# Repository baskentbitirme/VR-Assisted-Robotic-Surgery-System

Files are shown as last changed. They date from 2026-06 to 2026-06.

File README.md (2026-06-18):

TR

Eğitim ve Araştırma Uygulamaları İçin VR Destekli Robotik Cerrahi Eğitim Platformu

Bu proje, sağlık bilimleri ve mühendislik eğitiminde kullanılan yüksek maliyetli robotik sistemlere erişilebilir bir alternatif oluşturmak amacıyla geliştirilmiş hibrit bir eğitim ve araştırma platformudur. Sistem; Sanal Gerçeklik (VR), yapay zekâ destekli görüntü işleme, kablosuz haberleşme ve 3B yazıcıyla üretilmiş robotik bir kolu tek bir ekosistemde bir araya getirmektedir.

Proje kapsamında Berlin Charité Hastanesi'nden elde edilen fotogrametrik tarama verileri kullanılarak gerçekçi bir ameliyathane ortamı oluşturulmuş ve Unity tabanlı VR simülasyonuna entegre edilmiştir. Simülasyon ortamı tamamen açık kaynaklı teknolojiler, açık veri kaynakları ve açık erişimli varlıklar kullanılarak geliştirilmiştir.

Fiziksel robot kol tasarımı, açık kaynaklı BCN3D Moveo platformu temel alınarak yeniden modellenmiş ve eğitim senaryosunun ihtiyaçlarına uygun şekilde optimize edilmiştir. Orijinal çok eksenli yapı sadeleştirilerek 3 serbestlik dereceli (3-DoF) bir mimariye dönüştürülmüş ve tamamen 3B yazıcı teknolojileri kullanılarak üretilmiştir.

Sistemde iki farklı veri akışı eş zamanlı olarak çalışmaktadır. Kullanıcının VR ortamında seçtiği cerrahi alet bilgisi, XBee tabanlı kablosuz haberleşme altyapısı üzerinden fiziksel sisteme aktarılır. Aynı anda Grove Vision AI ve YOLOv8 tabanlı görüntü işleme sistemi çalışma alanındaki cerrahi aletleri gerçek zamanlı olarak algılar ve konum bilgilerini üretir. Merkezi kontrol birimi, VR tarafından gönderilen hedef nesne bilgisi ile yapay zekâ sisteminden gelen konum verilerini eşleştirerek robot kolun doğru nesneyi kavramasını ve doğru hedef noktaya taşımasını sağlar.

Bu yaklaşım sayesinde proje yalnızca bir VR simülasyonu veya yalnızca bir robot kol çalışması olmaktan çıkarak; sanal ortam, yapay zekâ algılama sistemi ve fiziksel robotu gerçek zamanlı olarak birleştiren bir Dijital İkiz (Digital Twin) platformuna dönüşmektedir.

Kullanılan Başlıca Teknolojiler

- Unity 6
- OpenXR
- YOLOv8
- Grove Vision AI V2
- XBee (IEEE 802.15.4)
- Arduino Mega
- ESP32
- BCN3D Moveo (Open Source Reference Architecture)
- Fusion 360
- 3D Printing Technologies

Proje Ekibi

Ayşe Sena ŞAHİN

Ceren Sena ALTUĞ

Nehir DÖLER

Nehir ERDEN

Sıla Nur SÖNMEZ

Yiğit Kemal YEŞİLTAŞ

Danışmanlar

Prof. Dr. Sedat NAZLIBİLEK

Prof. Dr. Ziya TELATAR

Dr. Öğr. Üyesi Onur KOÇAK

Not

Bu proje geliştirilirken literatür araştırması, yazılım geliştirme, hata ayıklama, dokümantasyon ve teknik doğrulama süreçlerinin çeşitli aşamalarında yapay zekâ araçlarından destek alınmıştır.

--------------------------------------------------------------

EN

VR-Assisted Robotic Surgical Training Platform for Educational and Research Applications

This project is a hybrid educational and research platform developed as an accessible alternative to high-cost robotic systems used in healthcare and engineering education. The system combines Virtual Reality (VR), AI-powered computer vision, wireless communication, and a 3D-printed robotic arm within a single integrated ecosystem.

A realistic operating room environment was reconstructed using photogrammetric data acquired from Berlin Charité Hospital and integrated into a Unity-based VR simulation. The virtual environment was developed entirely using open-source technologies, open datasets, and openly available digital assets.

The physical robotic arm was redesigned based on the open-source BCN3D Moveo platform and optimized for the educational objectives of the project. The original multi-axis architecture was simplified into a three-degree-of-freedom (3-DoF) robotic system and manufactured using additive manufacturing technologies.

The system operates through two simultaneous data streams. The surgical instrument selected by the user inside the VR environment is transmitted to the physical platform via an XBee-based wireless communication network. At the same time, a Grove Vision AI and YOLOv8-powered perception system continuously detects surgical instruments within the workspace and generates real-time positional data. The central control unit correlates the target object selected in VR with the position data provided by the AI vision system, enabling the robotic arm to identify, grasp, and transport the correct instrument to the designated destination.

By combining immersive VR interaction, AI-based perception, and physical robotic actuation, the project goes beyond a conventional simulation environment and evolves into a Digital Twin platform where virtual and physical systems operate synchronously in real time.

Key Features

- Photogrammetry-based Operating Room Reconstruction
- Virtual Reality Surgical Training Environment
- Digital Twin Architecture
- AI-Powered Object Detection and Localization
- Real-Time Wireless Communication
- Autonomous Instrument Identification and Handling
- Open-Source-Based Robotic System Design
- Low-Cost and Reproducible Educational Platform

Technologies

- Unity 6
- OpenXR
- YOLOv8
- Grove Vision AI V2
- XBee (IEEE 802.15.4)
- Arduino Mega
- ESP32
- BCN3D Moveo (Open-Source Reference Architecture)
- Fusion 360
- 3D Printing Technologies

Project Team

Ayşe Sena ŞAHİN

Ceren Sena ALTUĞ

Nehir DÖLER

Nehir ERDEN

Sıla Nur SÖNMEZ

Yiğit Kemal YEŞİLTAŞ

Supervisors

Prof. Dr. Sedat NAZLIBİLEK

Prof. Dr. Ziya TELATAR

Asst. Prof. Dr. Onur KOÇAK

Acknowledgement

This project was developed with support from various artificial intelligence tools during selected stages of literature review, software development, debugging, documentation, and technical validation.

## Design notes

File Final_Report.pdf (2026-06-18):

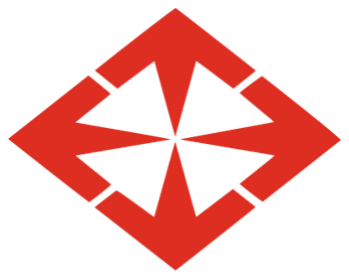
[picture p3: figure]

BAŞKENT ÜNİVERSİTESİ MÜHENDİSLİK FAKÜLTESİ BİTİRME PROJESİ RAPORU

EĞİTİM VE ARAŞTIRMA UYGULAMALARI İÇİN VR DESTEKLİ 3B

YAZICIYLA ÜRETİLMİŞ ROBOTİK CERRAHİ SİSTEMİNİN TASARIMI,

SİMÜLASYONU VE UYGULANMASI

Sıla Nur SÖNMEZ 22297548 & 22340070

Ayşe Sena ŞAHİN 22297606

Nehir DÖLER 22295597

Yiğit Kemal YEŞİLTAŞ 22298241

Ceren Sena ALTUĞ 22294442

Nehir ERDEN 22295777

Bölümü: Elektrik-Elektronik Mühendisliği

Proje Danışmanı: Prof. Dr. Sedat NAZLIBİLEK, Prof. Dr. Ziya TELATAR, Dr. Öğr. Üyesi Onur KOÇAK

Ders Kodu ve Adı: EEM 496 Bitirme Projesi II

Proje Başlangıcı: 2025-2026 Bahar Proje Süresi (Yarıyıl):2

Rapor Sunumu: 2025-2026 Bahar

i

Doküman No: MF-F-FRM-KONTROL EEM | Revizyon Tarihi: Revizyon Numarası:
Sayfa Sayısı: 1/1 | Uygulama Tarihi: 25.04.2018

BAŞKENT ÜNİVERSİTESİ MÜHENDİSLİK FAKÜLTESİ ELEKTRİK-ELEKTRONİK MÜHENDİSLİĞİ BÖLÜMÜ

BİTİRME PROJESİ RAPOR KONTROL FORMU

2025- 2026 BAHAR YARIYILI
Projenin Başlığı | Eğitim ve Araştırma Uygulamaları için VR destekli 3B Yazıcıyla Üretilmiş Robotik Cerrahi Sisteminin Tasarımı, Simülasyonu ve Uygulaması
Öğrenci | SILA NUR SÖNMEZ
Öğrenci | AYŞE SENA ŞAHİN
Öğrenci | NEHİR DÖLER
Öğrenci | YİĞİT KEMAL YEŞİLTAŞ
Öğrenci | CEREN SENA ALTUĞ
Öğrenci | NEHİR ERDEN

Ders
Kodu | EEM496
Proje | Süresi
(Yarıyıl) | 2 | Kaçıncı Yarıyıl | 2

Raporda Mutlaka Bulunması Gereken Kısımların Kontrolü:
Bölüm | Kontrol
Yazış biçimi uygun.
Dış kapak ve sunuş biçimi uygun.
Giriş bölümü var.
Yapılan çalışmayı anlatan bölümler var.
Proje çalışmasının gerçekçi kısıtlar altında yapıldığını anlatan bölümler var ve yeterli. (Proje işleyiş prosedürü genel esaslar madde 3’e göre incelenmelidir.)

Sonuçlar bölümü var.
Kaynakça var.

ii

Adı Soyadı | İmza
Proje Danışmanı | Ziya TELATAR
Proje Danışmanı | Sedat NAZLIBİLEK
Proje Danışmanı | Onur KOÇAK

iii

BİTİRME PROJESİ ONAY FORMU

Eğitim ve Araştırma Uygulamaları için VR destekli 3B Yazıcıyla Üretilmiş Robotik Cerrahi Sisteminin Tasarımı, Simülasyonu ve Uygulaması başlıklı bitirme projesi raporu kapsam ve niteliği açısından tarafımızdan incelenmiş ve kabul edilmiştir.

| Unvan- İsim Soy isim | İmza
DANIŞMAN | Prof. Dr. Sedat NAZLIBİLEK
DANIŞMAN | Prof. Dr. Ziya TELATAR
DANIŞMAN | Dr. Öğr. Üyesi Onur KOÇAK
JÜRİ ÜYESİ | Doç. Dr. Selda GÜNEY
JÜRİ ÜYESİ | Dr. Öğr. Üyesi Gülşah DEMİRHAN AYDIN
JÜRİ ÜYESİ | Dr. Öğr. Üyesi Deniz KARAÇOR
JÜRİ ÜYESİ | Dr. Öğr. Üyesi Bülent İRFANOĞLU

iv

TEŞEKKÜR

Bu çalışma sürecinde, ihtiyacımız olduğu anlarda yardımını esirgemeyen Prof. Dr. Ziya TELATAR, Prof. Dr. Sedat NAZLIBİLEK, Dr. Öğr. Üyesi Onur KOÇAK hocalarımıza ve projenin yürütülmesi sürecinde sağladıkları teknik altyapı ve destek için Marla Teknoloji Mühendislik Ltd. Şti.’ye çok teşekkür ederiz.

v

ÖZ

Günümüzde sağlık bilimleri ve mühendislik eğitiminde kullanılan yüksek maliyetli ticari robotik sistemlere erişim, kurumların büyük çoğunluğu için ciddi bir engel teşkil etmektedir. Bu çalışmada söz konusu probleme çözüm olarak; sanal gerçeklik (VR) destekli, yapay zekâ tabanlı görüntü işleme entegreli, düşük maliyetli ve yeniden üretilebilir bir robotik medikal lojistik eğitim platformu tasarlanmış, geliştirilmiş ve doğrulanmıştır.

Platformun mekanik tasarımı, açık kaynaklı BCN3D Moveo mimarisi referans alınarak Fusion 360 ortamında yeniden modellenmiş; orijinal 6 eksenli yapı, projenin gereksinimlerine göre taban, omuz ve dirsek olmak üzere 3 serbestlik dereceli (3-DoF) bir kola dönüştürülmüş ve Bambu Lab üç boyutlu yazıcı ile eSun PLA+, PLA ve ABS filamentler kullanılarak üretilmiştir. Motor konfigürasyonunda; taban ekseninde tork kararlılığı için uzun gövdeli bir Nema 17, omuz ekseninde yüksek yük kapasitesi sağlamak amacıyla paralel çalışan iki adet Nema 23 ve dirsek ekseninde 3B baskı ile üretilmiş 4:1 gezegen dişlisiyle desteklenmiş bir adet Nema 17 adımlı motor tercih edilmiştir. Uç efektördeki tutucu (gripper) mekanizması MG996R servo motor ile kontrol edilmekte; tüm motorlar RAMPS 1.4 kontrol kartı ve dört adet TB6600 sürücüsü aracılığıyla yönetilmektedir. Gömülü yazılım katmanında motorların kesintisiz ve zamanlaması hassas biçimde çalışabilmesi için donanımsal zamanlayıcı kesmesi (Timer5 Interrupt) altyapısı benimsenmiş; süreç yönetimi asenkron durum makinesi (state machine) yapısıyla kurgulanmıştır.

Sistemin genel çalışma akışı şu şekilde işlemektedir: Kullanıcı, Unity 3D oyun motoru ve OpenXR altyapısıyla geliştirilen sanal ameliyathane ortamında cerrahi aletlerle etkileşime girerek bir lojistik komut başlatır. Bu komut, VR İstasyonundan XBee modülleri (IEEE 802.15.4, nokta-nokta topoloji) aracılığıyla kablosuz olarak fiziksel robota iletilir. Eş zamanlı olarak, Grove Vision AI Modülü ve Raspberry Pi kamerasından oluşan görüntü işleme birimi, YOLOv8 modeli ile çalışma alanındaki hemostat, penset, steril kompres ve kontamine kompres gibi cerrahi aletleri gerçek zamanlı olarak tanımlar ve elde edilen (x_center, y_center) piksel koordinatlarını donanımsal seri port (Serial1) üzerinden Arduino Mega'ya iletir. Arduino Mega bu koordinatları, XBee (Serial2) üzerinden gelen taşıma emirleriyle eşleştirerek bilineer koordinat dönüşüm matematiği yardımıyla motor adım sayılarına çevirir ve robotik kol nesneyi hedef medikal sokete başarıyla yerleştirir. Tüm bu süreçte işlem yükü; VR simülasyonunu yürüten VR İstasyonu ile robot tarafındaki güç yönetimi ve kamera veri hatlarını denetleyen Yerel İzleme İstasyonu arasında dağıtık bir mimariyle paylaştırılmıştır. Seri iletişimde (UART) paket kaybını önlemek amacıyla dinamik veri çerçeve yapısı uygulanmıştır.

Geliştirilen bu hibrit platform; düşük gecikmeli kablosuz iletişim, gerçek zamanlı entegrasyon ve gelişmiş görüntü işleme yeteneklerini bir arada sunarak medikal malzeme yönetimi süreçlerinin eğitiminde güvenli, tekrarlanabilir ve erişilebilir bir alternatif oluşturmaktadır.

vi

ABSTRACT

Access to robotic training systems in health sciences and engineering education remains a practical challenge for most institutions due to the high cost of commercial alternatives. This study presents the design, development, and validation of a low-cost, reproducible robotic medical logistics training platform that combines virtual reality (VR) with AI-based visual perception.

The mechanical structure was designed in Fusion 360 by adapting the open-source BCN3D Moveo architecture, reducing the original six-axis configuration to a three-degree-of-freedom (3-DoF) arm with base, shoulder, and elbow axes. The arm was fabricated using a Bambu Lab 3D printer with eSun PLA+, PLA, and ABS filaments. A long-body Nema 17 motor drives the base axis, two parallel Nema 23 motors handle the shoulder axis for higher load demands, and a Nema 17 motor paired with a 3D-printed 4:1 planetary gearbox drives the elbow. All stepper motors are controlled through a RAMPS 1.4 board and four TB6600 drivers, while the end-effector gripper is actuated by a MG996R servo motor. On the firmware side, a hardware timer interrupt (Timer5 Interrupt) ensures precise and uninterrupted motor stepping, with overall process flow managed through an asynchronous state machine.

The system operates as follows. The user interacts with surgical instruments inside a virtual operating room built with Unity 3D and OpenXR, generating a logistics command. That command travels wirelessly from the VR Station to the physical robot over XBee modules (IEEE 802.15.4, point-to-point). At the same time, a Grove Vision AI Module and Raspberry Pi camera run a YOLOv8 model that continuously detects surgical tools including hemostats, forceps, sterile compresses, and contaminated compresses, sending their (x_center, y_center) pixel coordinates to the Arduino Mega over Serial1. The Arduino Mega correlates those coordinates with the incoming transport command from XBee (Serial2), applies bilinear coordinate transformation to convert pixel positions into motor step counts, and drives the arm to place the target object into the correct medical socket. To distribute computational load and maintain physical independence, the architecture splits responsibility between the VR Station handling simulation and a Local Monitoring Station managing power and camera data near the robot. A dynamic UART frame structure guards against packet loss throughout.

The resulting platform brings together low-latency wireless communication, real-time object detection, and immersive VR interaction in a single reproducible system, offering a practical and accessible training environment for medical material handling procedures.

vii

İÇİNDEKİLER

2.1.2. Ara dönem sonrası yapılan mimari değişiklikler ve sistem

viii

ix

2.5.1. Asenkron durum yönetimi ve komut işleme mantığı | 58
2.5.2. Ara dönem sonrası yapılan mimari değişiklikler ve gerekçeleri........58
3. PROJENİN DEĞERLENDİRİLMESİ | 60
3.1. Proje İş Planı ve Yönetimi | 60
3.2. Projenin Maliyeti ve Ekonomik Açıdan Değerlendirilmesi | 61
3.3. Kullanılan veya Dikkate Alınan Mühendislik Standartları | 64
3.4. Projenin Gerçekçi Tasarım Kriterleri Açısından Değerlendirilmesi .........65
3.4.1. Gerçekçi kısıtlar ve koşullar | 65
3.4.2. Sürdürülebilirlik | 65
3.4.3. Üretilebilirlik | 66
3.4.4. Sağlık | 66
3.4.5. Çevresel etkiler | 66
3.4.6. Güvenlik | 67
3.4.7. Etik | 67
3.4.8. Sosyal ve politik sorunlar | 67
3.4.9. Yaygınlık | 67
3.4.10. Özgünlük | 67
3.4.11. Girişimcilik | 67
3.4.12. Yenilikçilik | 68
4. SONUÇ | 69
EK-A: Kavram Tanımlama ve İşletimi (KTİD) Belgesi | 71
EK-B: Proje İsterleri Belirtimi (PİBD) Belgesi | 72
EK-C: Proje Uygulama Takvimi (PRUT) | 73
EK-D: Genel Mimari Tasarımı (PMTD) Belgesi | 76
EK-E: Proje Risk Tanımlama (PRTD) Belgesi | 77
EK-F: IEEE Etik Kuralları | 79
EK-G: Standartlar ve Kısıtlar Belgesi | 80
EK-H: Disiplinler Arası Çalışma Belgesi | 81
EK-I: Öğrenci Özgeçmişleri | 82
EK-J: Yazılım Kaynak Kodları ve Dijital Dokümantasyon | 84
KAYNAKÇA | 85

x

TABLOLAR DİZİNİ

Tablo 1 Maliyet Analizi Bölüm 1 | 62
Tablo 2 Maliyet Analizi Bölüm 2 | 62
Tablo 3 Maliyet Analizi Bölüm 3 | 63
Tablo 4 Maliyet Analizi Bölüm 4 | 63
Tablo 5 Maliyet Analizi Bölüm 5 | 64
Tablo 6 Proje Uygulama Takvimi Bölüm 1 | 73
Tablo 7 Proje Uygulama Takvimi Bölüm 2 | 74
Tablo 8 Proje Uygulama Takvimi Bölüm 3 | 75
Tablo 9 Risk Analizi Bölüm 1 | 77
Tablo 10 Risk Analizi Bölüm 2 | 77
Tablo 11 Risk Analizi Bölüm 3 | 78

xi

ŞEKİLLER DİZİNİ

xii

SİMGELER VE KISALTMALAR DİZİNİ

3B / 3D: Üç Boyutlu
ADC (Analog-to-Digital Converter): Analog-Dijital Dönüştürücü
API (Application Programming Interface): Uygulama Programlama Arayüzü
BAUD: Seri Haberleşme Hız Birimi (115200 Baud vb.)
CAD (Computer Aided Design): Bilgisayar Destekli Tasarım
C# (C-Sharp): Unity platformu içerisinde kullanılan programlama dili
COM (Communication Port): Bilgisayar üzerindeki seri haberleşme portu DoF (Degrees of Freedom): Serbestlik Derecesi (Robot kolun hareket ekseni sayısı)
FPS (Frames Per Second): Saniyedeki Kare Sayısı (Simülasyonun akıcılık değeri)
GND (Ground): Elektriksel Topraklama
GUI (Graphical User Interface): Grafik Kullanıcı Arayüzü
HMD (Head-Mounted Display): Başa Takılı Ekran (VR Gözlüğü)
IDE (Integrated Development Environment): Tümleşik Geliştirme Ortamı (Arduino IDE)
IEEE (Institute of Electrical and Electronics Engineers): Elektrik ve Elektronik Mühendisleri Enstitüsü
IP (Internet Protocol): İnternet Protokolü
KTİD: Kavram Tanımı ve İşletimi Dokümanı
LDO (Low-Dropout): Düşük Gerilimli Regülatör (Donanım beslemesi için) MCU (Microcontroller Unit): Mikrodenetleyici Birimi (Arduino Nano/Uno vb.) PC (Personal Computer): Kişisel Bilgisayar
PLA (Polylactic Acid): 3B yazıcıda kullanılan organik baskı materyali
POT: Potansiyometre (Robot koldaki açısal veriyi okuyan sensör)
PRTD: Proje Risk Tanımlama Dokümanı
PRUT: Proje Uygulama Takvimi
PWM (Pulse Width Modulation): Sinyal Genişlik Modülasyonu
RAM (Random Access Memory): Rastgele Erişimli Bellek
SDK (Software Development Kit): Yazılım Geliştirme Kiti (Oculus/Meta SDK vb.)
UART (Universal Asynchronous Receiver-Transmitter): Seri haberleşme protokolü
UI (User Interface): Kullanıcı Arayüzü
USB (Universal Serial Bus): Evrensel Seri Veri Yolu
VCC (Voltage Common Collector): Devre Besleme Gerilimi (+5V) VR (Virtual Reality): Sanal Gerçeklik

### 1. GİRİŞ

Günümüz sağlık bilimleri ve mühendislik eğitiminde, gelişen robotik teknolojilerin lojistik ve malzeme yönetimi süreçlerine entegrasyonu büyük bir ivme kazanmıştır. Bu bitirme projesi kapsamında ele alınan “Eğitim ve Araştırma Uygulamaları için VR Destekli 3B Yazıcıyla Üretilmiş Robotik Sisteminin
Tasarımı, | Simülasyonu | ve | Uygulaması” | ( | Design, | Simulation, | and
Implementation of a VR-Assisted 3D-Printed Robotic System for Educational and Research Applications) başlıklı çalışma; sağlık sektörü standartlarına uygun medikal lojistik süreçlerinin, düşük maliyetli donanımlar ve sürükleyici sanal gerçeklik ortamları üzerinden simüle edilmesini sağlayan çok disiplinli bir mühendislik yaklaşımıdır.

Projenin temel konusu; cerrahi eğitim ortamlarında ve tıbbi malzeme yönetiminde maliyet bariyerini ortadan kaldırmak amacıyla, mekanik aksamı 3B yazıcı teknolojisiyle üretilen 3 serbestlik dereceli (3-DoF) bir robotik manipülatörün, sanal gerçeklik (VR) ortamıyla eş zamanlı ve kablosuz kontrolünü sağlayan dağıtık bir ekosistem geliştirmektir. Bu çalışma; sanal gerçeklik, gömülü sistemler, kablosuz haberleşme ve yapay zekâ tabanlı görüntü işleme tekniklerini tek bir potada eriterek geleceğin sağlık bilimleri ve mühendislik öğrencilerinin çok daha erişilebilir ve güvenli koşullarda, gerçekçi bir medikal lojistik (tut-bırak) eğitimi alabileceği bütünleşik bir platform sunmaktadır

### 1.1. Motivasyon ve Mevcut Durum Analizi

Sağlık bilimleri eğitiminde, medikal malzemelerin ve cerrahi aletlerin (hemostat, penset, kompres vb.) doğru, hızlı ve sterilizasyon kurallarına uygun bir şekilde yönetilmesi (pick and place) operasyonel süreçlerin başarısı için kritik bir öneme sahiptir. Ancak eğitim kurumlarında bu süreçlerin pratik edilmesi amacıyla kullanılan ticari robotik sistemlerin milyon dolarlık yüksek yatırım maliyetleri ve kapalı mimarileri, bu teknolojilerin geniş öğrenci kitlelerine ulaştırılmasını imkânsız kılmaktadır. Mevcut simülasyon ve eğitim yazılımları incelendiğinde ise çalışmaların çoğunlukla sadece sanal katmanda kaldığı, öğrencilere fiziksel bir manipülasyon ve senkronizasyon deneyimi sunamadığı görülmektedir.

Bu projenin temel motivasyonu; güncel donanım mimarilerini ve hızlı prototipleme yöntemlerini kullanarak, Türkiye’de medikal malzeme lojistiği ve robotik eğitimine yönelik yerli, modüler, güvenli ve ekonomik bir hibrit simülatör altyapısı oluşturmaktır. Tasarlanan sistem; operatörün sanal dünyadaki (VR) malzeme taşıma emirlerini, kablosuz ağ üzerinden fiziksel bir manipülatöre aktararak gerçek zamanlı bir teleoperasyon ve eğitim deneyimi sunmayı, böylece eğitimdeki öğrenme eğrisini daha verimli hale getirmeyi amaçlamaktadır.

### 1.2. Proje Kapsamındaki Teknolojik Katmanlar

Sistemin bütünleşik, kararlı ve yüksek performanslı bir yapıda çalışabilmesi adına dört temel teknolojik katman üzerinde çalışmalar yürütülmüş ve bu katmanlar dağıtık bir kontrol mimarisiyle birleştirilmiştir:

- Sanal Gerçeklik (VR) ve Simülasyon Katmanı: Unity 3D oyun motoru ve OpenXR altyapısı kullanılarak, kullanıcının cerrahi aletler ve lojistik soketlerle etkileşime girebildiği sürükleyici bir sanal ameliyathane ortamı kurgulanmıştır.
- Mekanik Tasarım ve İmalat Katmanı: Açık kaynaklı BCN3D Moveo mimarisi referans alınarak Fusion 360 ortamında tasarım kriterlerine göre yeniden modellenen gövde, 3 serbestlik dereceli (3-DoF) hareket kabiliyetine sahip bir kol yapısına dönüştürülmüştür. Fiziksel gövde; Bambu Lab 3B yazıcı kullanılarak eSun PLA+, PLA ve ABS filamentlerle hafif, modüler ve bakımı kolay olacak şekilde imal edilmiştir. Mekanik tork kararlılığını sağlamak adına taban ekseninde uzun gövdeli bir Nema 17, omuz ekseninde paralel ve karşılıklı çalışan iki adet Nema 23 ve dirsek ekseninde dişli kutusu (gearbox) destekli bir Nema 17 adımlı motor yerleştirilmiştir. Tüm adımlı motorlar, RAMPS 1.4 kontrol kartı üzerinden dört adet TB6600 sürücüsü aracılığıyla kontrol edilmektedir. Uç efektörde ise nesne kavrama işlevi için MG996R servo motorlu bir tutucu (gripper) mekanizması entegre edilmiştir.
- Gömülü Kontrol ve Donanım Katmanı: RAMPS 1.4 genişleme kartı ile donatılmış Arduino Mega ana kontrolör mimarisi üzerine kurulan bu katmanda; motorların sarsıntısız, yüksek hassasiyetle ve kesintisiz sürülebilmesi amacıyla işlemci seviyesinde donanımsal zamanlayıcı kesmesi (Timer5 Interrupt) altyapısı ve asenkron durum makinesi (state machine) yazılımı geliştirilmiştir. İşlem yükünü optimize etmek amacıyla sistem çift bilgisayarlı bir dağıtık mimariye bölünmüştür; VR istasyonundan gelen taşıma emirleri XBee modülleri (IEEE 802.15.4 standardında) ile sahaya kablosuz iletilirken, yerel izleme istasyonuna bağlı donanımlar arasında paket kaybını önlemek amacıyla dinamik veri çerçeveli (UART) bir iletişim protokolü uygulanmıştır.
- Yapay Zekâ ve Görüntü İşleme Katmanı: Grove Vision AI modülü ve Raspberry Pi kamera donanımı üzerinde koşturulan YOLOv8 yapay zekâ modeli sayesinde; hemostat, penset, steril kompres ve kontamine kompres gibi nesneler gerçek zamanlı olarak algılanmaktadır. Elde edilen piksel koordinatları, ana kontrolörde bilineer koordinat dönüşüm matematiği ile motor adım sayılarına çevrilerek otonom, dinamik ve yüksek kararlılıkta bir tut-bırak (pick and place) kalibrasyonu sağlanmıştır.

### 1.3. Projenin Amaçları ve Hedefleri

Proje kapsamında doğrulanması hedeflenen ve başarıyla gerçekleştirilen temel kriterler şu şekildedir:

- Mekanik olarak stabil, eksen yükleri dengelenmiş ve medikal malzeme taşıma hassasiyetini karşılayabilecek bir robotik manipülatör prototipi gerçekleştirmek.
- Tamamen bağımsız çalışan VR bilgisayarı ile fiziksel robot istasyonu arasında XBee modülleri üzerinden düşük gecikmeli kablosuz haberleşme kurarak gerçek zamanlı teleoperasyon sağlamak.
- Yapay zekâ tabanlı YOLOv8 modeliyle hedef medikal malzemelerin anlık konum ve sınıf takibini yüksek doğruluk oranlarıyla gerçekleştirmek.
- Seri iletişim hatlarında veri paket kaybını önleyici dinamik veri yapıları (data framing) kullanarak robotun asenkron durumlar karşısındaki kararlılığını korumak.
- Sağlık bilimleri araştırmaları ve mühendislik laboratuvarları için ticari muadillerine kıyasla son derece düşük maliyetli, yeniden üretilebilir ve modüler bir AR-GE platformu sunmak.

Projenin temel vizyonu, operasyonel senaryoları ve kullanıcı etkileşim süreçleri hakkında daha detaylı bilgi EK-A: Kavram Tanımlama ve İşletimi (KTİD) belgesinde sunulmuştur. Sistemin teknik ve fonksiyonel gereksinimlerinin detaylı listesi ise EK-B: Proje İsterleri Belirtimi (PİBD) içerisinde yer almaktadır.

### 1.4. Literatür Araştırması

- Robotik Cerrahide Endüstriyel Standart: Da Vinci (Intuitive Surgical)

Robotik sistemlerin tıp dünyasındaki tarihsel gelişimi incelendiğinde, Intuitive Surgical firması tarafından geliştirilen Da Vinci sistemi, uzaktan yönetim platformlarının "altın standardı" olarak kabul edilmektedir. Mühendislik perspektifinden bakıldığında Da Vinci, operatörün fiziksel olarak çalışma sahasından bağımsız bir konsolda oturduğu ve robotik kolları bir "Master-Slave" (Efendi-Köle) mimarisi üzerinden yönettiği bir tele-operasyon (uzaktan kontrol) platformudur.

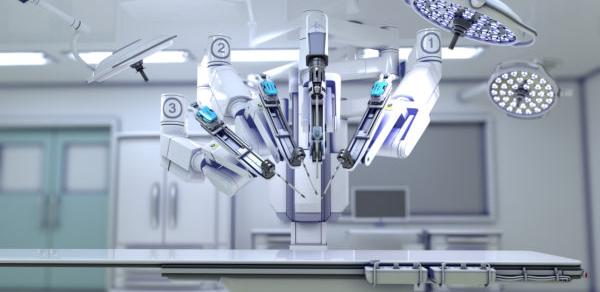
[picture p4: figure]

Şekil 1 Da Vinci Robotu

Şekil 1’deki Da Vinci robotuna ait sistemin literatürde en çok öne çıkan teknik özellikleri şunlardır:

### 1. EndoWrist Teknolojisi: İnsan elinin anatomik kısıtlarını aşarak 7

serbestlik dereceli (DoF) hareket imkânı sunar, bu da dar alanlarda yüksek manevra kabiliyeti sağlar [1].

### 2. Titreme Filtreleme: Cerrahın elindeki mikro-titremeleri algoritmik olarak

sönümleyerek cerrahi sahaya pürüzsüz bir hareket iletir [2].

3. 3B Yüksek Çözünürlüklü Görüntüleme: Cerrahın derinlik algısını maksimize eden binoküler bir görüntüleme sistemi sunar.

Ancak akademik çalışmalar, bu sistemin yüksek maliyet bariyeri (milyon dolarlık kurulum ve bakım masrafları) ve kapalı kaynak mimarisi nedeniyle eğitim kurumlarında her öğrenciye sunulmasının imkânsız olduğunu vurgulamaktadır. Projemiz, bu noktada Da Vinci'nin sunduğu dağıtık tele-operasyon ve Master-Slave kontrol mantığını temel alarak; malzeme yönetimi ve lojistik süreçlerini, 3B yazıcı teknolojisi ve açık kaynaklı gömülü kontrolcülerle minimize eden alternatif ve erişilebilir bir model sunmaktadır.

- Eğitimde Oyunlaştırma ve Surgery Quest Platformu

Cerrahi eğitimde sadece mekanik hassasiyet değil, operasyonel prosedürlerin ve sterilizasyon kurallarının öğrenilmesi de kritik öneme sahiptir. Literatürde "Serious Games" (Ciddi Oyunlar) olarak tanımlanan kategorinin cerrahi eğitimdeki en dikkat çekici örneklerinden biri "Surgery Quest" oyunudur [3].

Surgery Quest, cerrah adaylarına şu yetkinlikleri kazandırmayı amaçlar:

### 1. Prosedürel Akış: Ameliyat öncesi hazırlıktan operasyon sonuna kadar

olan süreci bir oyun kurgusu içerisinde öğretir [4].

### 2. Mekânsal Farkındalık: Kullanıcının ameliyathane içerisindeki nesnelerle

etkileşime girerek çevreye adaptasyonunu sağlar.

### 3. Karar Verme Süreçleri: Yanlış alet seçimi veya prosedür hatası

durumunda anlık geri bildirim vererek öğrenme eğrisini hızlandırır [5].

Mühendislik açısından Surgery Quest ve benzeri simülasyonların en büyük eksikliği, çalışmaların sadece yazılım katmanında kalması ve fiziksel bir manipülatörle (robot kol) gerçek zamanlı bir bağ kurmamasıdır. Projemiz
kapsamında | geliştirilen | sanal | ameliyathane | simülasyonu, | yüksek
gerçeklikteki sanal ortamı, kablosuz haberleşme ağı üzerinden fiziksel bir 3-DoF robotik kol ile senkronize ederek literatürdeki "oyunlaştırma" mantığını fiziksel bir "uygulama ve pick-and-place" katmanına taşımaktadır. Şekil 2’de Surgery Quest’e ait simülasyondan bir ekran görüntüsüne yer verilmiştir.

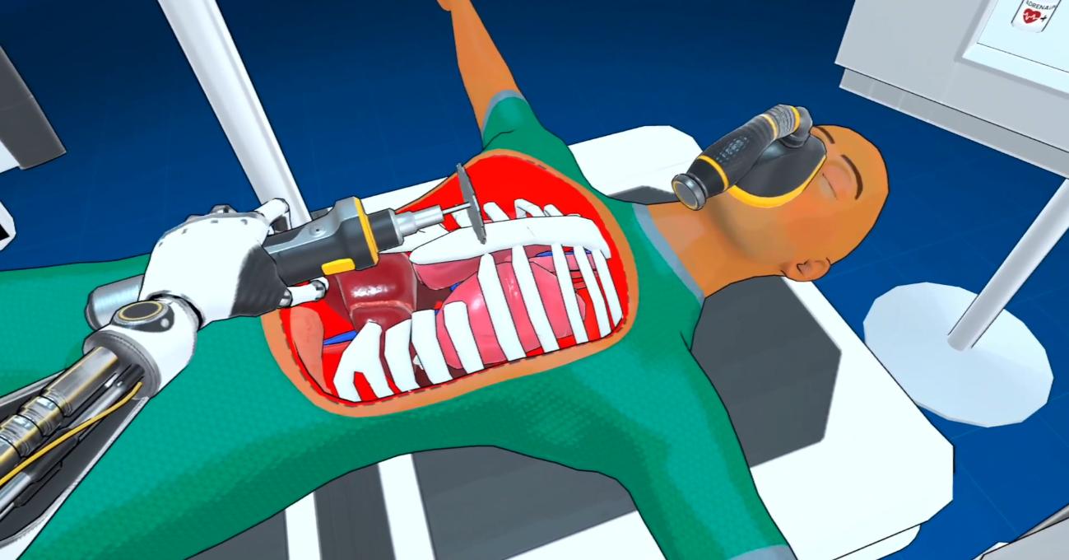
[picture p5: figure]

Şekil 2 Simülasyon

### 1.4.1. Sanal gerçeklik ve dijital ikiz entegrasyonu

Sanal Gerçeklik (VR) teknolojisinin eğitimdeki etkinliği, literatürde el-göz koordinasyonu ve nesne manipülasyon becerilerinin kazanılma süresini kısalttığını gösteren çalışmalarla desteklenmektedir. Geleneksel simülatörler çoğunlukla statik ve jenerik modeller kullanırken, güncel araştırmalar fiziksel unsurların dijital ortama aktarılmasının kullanıcı üzerindeki "orada olma" (presence) hissini önemli ölçüde artırdığını ortaya koymaktadır. Bu kapsamda, Şekil 2'de örnek bir cerrahi eğitim sanal ortamı gösterilmektedir. Görüldüğü üzere kullanıcı, sanal bir ameliyathane içerisinde robotik cerrahi ekipmanlarla etkileşime geçebilmekte ve gerçek operasyon koşullarına benzer bir eğitim deneyimi yaşayabilmektedir.
Bu bağlamda projemizdeki tasarım yaklaşımı aşağıdaki iki temel akademik kavramı bir araya getirmektedir:

### 1. Dijital İkiz (Digital Twin) Mimarisi: Sanal ortamdaki robotun hareketleri

ile fiziksel dünyada 3B yazıcı kullanılarak üretilmiş robotun eş zamanlı ve senkronize şekilde çalışması.

### 2. Hacimsel Derinlik Algısı ve Gerçekçilik: Kullanıcının yalnızca görsel

olarak değil, işitsel unsurlarla da desteklenmesi. Ventilatör sesleri, kalp monitörü sinyalleri ve ameliyathane ortam sesleri gibi bileşenlerin kullanılmasıyla psikolojik gerçekçiliğin ve sürükleyiciliğin artırılması.

Bu entegrasyon sayesinde kullanıcıların hem teknik becerilerini geliştirmeleri hem de gerçek operasyon ortamına benzer koşullarda deneyim kazanmaları hedeflenmektedir.

### 1.4.2. Literatürdeki boşluk ve projemizin özgün değeri

Yapılan literatür taraması sonucunda; mevcut medikal robotik sistemlerin (Da Vinci vb.) kapalı mimarileri ve yüksek maliyetleri nedeniyle akademik araştırmalar ve öğrenci pratikleri için modüler bir yapı sunmadığı; Surgery Quest gibi simülasyonların ise donanım desteğinden yoksun olduğu görülmüştür.

Projemizde uygulanan Unity-XBee kablosuz tele-operasyon mimarisi, Arduino Mega üzerindeki donanımsal kesme (Timer5) tabanlı motor kontrolü ve ESP32 entegreli YOLOv8 algoritması tabanlı otonom nesne tespiti, düşük maliyetli sistemlerin de yüksek hassasiyet ve kararlılıkla çalışabileceğini kanıtlamaktadır. Tasarlanan bu çift bilgisayarlı dağıtık kontrol yapısı, literatürdeki yazılım-donanım kopukluğunu ortadan kaldırarak; sağlık bilimleri ve mühendislik eğitiminin demokratikleşmesine, aynı zamanda modüler ve yerli simülatör altyapılarının geliştirilmesine yönelik özgün bir akademik çözüm sunmaktadır.

### 2. PROJE KAPSAMINDA YAPILAN ÇALIŞMALAR

### 2.1. Genel Sistem Mimarisi

Tasarlanan robotik medikal lojistik eğitim platformu, yüksek performans, işlem yükü optimizasyonu ve modülerlik sağlamak amacıyla çift bilgisayarlı dağıtık bir kontrol ve simülasyon mimarisi üzerine kurgulanmıştır. Sistemsel döngü; sanal ortamdaki (VR) kullanıcı etkileşimlerinin ve taşıma emirlerinin, fiziksel sahaya kablosuz ağlar üzerinden asenkron aktarılması ve eş zamanlı olarak yapay zekâ tabanlı bir görüntü işleme katmanıyla çalışma alanındaki nesnelerin otonom denetimi prensiplerine dayanmaktadır.

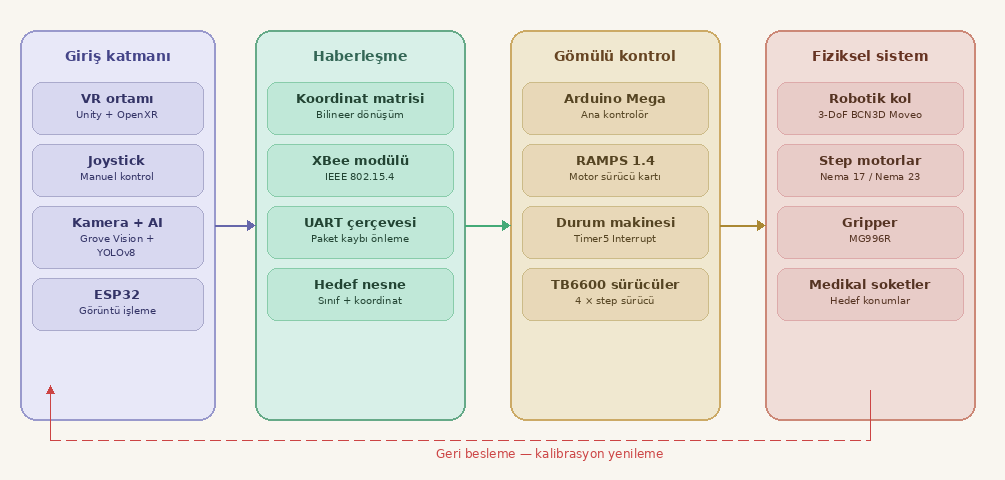
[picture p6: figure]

Şekil 3 Genel Sistem Mimarisi

Şekil 3'te sunulan genel sistem mimarisi şeması incelendiğinde, platformun hiyerarşik olarak iki ana istasyona ve üç temel teknolojik katmana ayrıldığı görülmektedir:

- VR İstasyonu (Birincil Bilgisayar): Unity 3D oyun motoru ve OpenXR API altyapısıyla bağımsız bir bilgisayar üzerinde yürütülen, kullanıcının medikal lojistik süreçlerini simüle ettiği sanal ameliyathane katmanıdır (Giriş Katmanı).
- Yerel İzleme İstasyonu (İkincil Bilgisayar) ve Donanım Sahası: Robot mekaniğinin hemen yanında konumlandırılan, donanımın güç yönetimini üstlenen, ESP32 kamera modülünün anlık veri akışı ile flaş mekanizmasını denetleyen izleme katmanıdır.
- Merkezi Mikrodenetleyici Katmanı: Donanımsal kesme (interrupt) altyapısına sahip Arduino Mega ana kontrolörü, RAMPS 1.4 genişleme kartı, endüstriyel TB6600 adımlı motor sürücüleri ve 3-DoF robotik kol bileşenlerinden oluşan fiziksel uygulama katmanıdır.

Bu dağıtık kontrol mimarisi sayesinde, VR simülasyonunun ihtiyaç duyduğu yoğun grafik işlem yükü ile sahadaki gerçek zamanlı görüntü işleme ve motor sürme görevleri farklı işlem birimlerine paylaştırılmıştır. Böylece tek bir işlemcinin aşırı yüklenmesinden (overhead) kaynaklanabilecek zamanlama gecikmeleri ve kararsızlıklar tamamen elimine edilmiştir.

### 2.1.1. Veri akış şeması ve haberleşme protokolü

Sistemin gerçek zamanlı performansını belirleyen en önemli parametre, asenkron veri hatlarının entegrasyonu ve port haritasının yönetimidir.

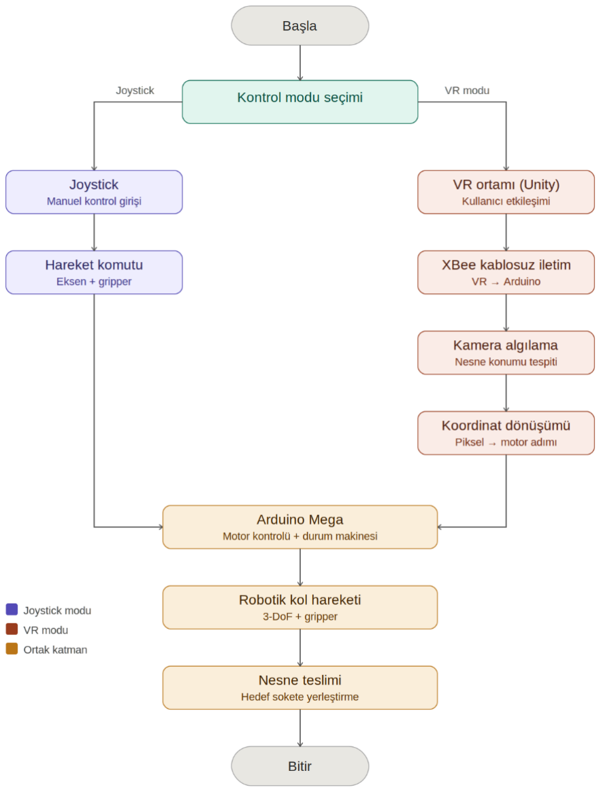
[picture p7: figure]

Şekil 4 Veri Akış Şeması

Şekil 4'te sunulan algoritma akış şemasına uygun olarak kurgulanıp işletilen veri akış süreci, kronolojik olarak şu adımları kapsamaktadır:

### 1. Kablosuz Teleoperasyon Hattı (VR-> Robot): Kullanıcı sanal

dünyada hedef medikal malzemeyle etkileşime geçtiğinde veya kontrol modunu seçtiğinde, VR İstasyonu asenkron bir lojistik komut paketi üretir. Bu paket, bilgisayara bağlı olan birinci XBee modülü üzerinden kablosuz olarak (IEEE 802.15.4 standardı, nokta-nokta topoloji) sahaya iletilir. Robot gövdesindeki alıcı XBee modülü veriyi yakalayarak, Arduino Mega'nın ikinci donanımsal seri portuna (Serial2, UART) aktarır. Manuel kontrol tercih edildiğinde ise joystick girdileri doğrudan eksen ve gripper hareket komutlarına dönüştürülerek ortak katmana ulaştırılır.

### 2. Otonom Nesne Algılama Hattı (Kamera-> Robot): Çalışma

sahasının üzerinde konumlandırılan Grove Vision AI Modülü ve Raspberry Pi kamera donanımı, yerleşik YOLOv8 yapay zekâ modeliyle cerrahi aletleri (hemostat, penset, steril kompres, kontamine kompres) gerçek zamanlı tarar. Yazılımsal filtrelerle kararlı kılınan hedef nesne sınıfı ve (x_center, y_center) piksel koordinatları, bağımsız çalışan ESP32 kamera modülü üzerinden Arduino Mega'nın birinci donanımsal seri portuna (Serial1, UART) iletilir.

### 3. Merkezi Paket Ayrıştırma ve Kinematik Kalibrasyon: İki farklı seri

portu asenkron olarak dinleyen Arduino Mega, UART hatlarındaki paket kayıplarını önlemek adına geliştirilen dinamik veri çerçeve yapısını (data framing) uygular. Ayrıştırma (parsing) algoritması, XBee'den gelen taşıma emri ile ESP32'den gelen anlık nesne koordinatlarını eşleştirir. Piksel cinsinden gelen iki boyutlu kamera koordinatları, bilineer koordinat dönüşüm matematiği vasıtasıyla robot kolun eklem uzayındaki motor adım sayılarına (steps) dinamik olarak dönüştürülür. Koordinatların yazılımsal sınır değerleri (limit switch sınırları) içerisinde olup olmadığı denetlenerek sistem güvenliği doğrulanır.

### 4. Donanımsal Kesme Tabanlı Sürüş (Donanım Çıktısı): Doğrulanan

adım sayıları ve yön bilgileri, RAMPS 1.4 kartı üzerinden TB6600
sürücülerine | aktarılır. | Motorların | sarsıntısız | ve | milisaniye
hassasiyetinde | tahrik | edilebilmesi | amacıyla, | gömülü | yazılım
katmanında Donanımsal Zamanlayıcı Kesmesi (Timer5 Interrupt) ve asenkron durum makinesi (state machine) mimarisi koşturulmaktadır. Bu sayede motor adımları arka planda kesintisiz bir rampa profiliyle sürülürken, uç efektördeki MG996R servo motorlu tutucu (gripper) tetiklenerek hedef nesne ilgili medikal sokete başarıyla yerleştirilir (pick and place).

### 2.1.2. Ara dönem sonrası yapılan mimari değişiklikler ve sistem

optimizasyonu

Projenin birinci döneminde (Ara Rapor sürecinde) öngörülen ilk mekanik ve elektronik altyapı, sistemin nihai aşamadaki gerçek zamanlılık, düşük gecikme ve yüksek işlem yükü gereksinimlerini karşılayabilmesi adına kapsamlı bir optimizasyon sürecinden geçirilmiştir. Bu doğrultuda, ara rapordan final aşamasına kadar gerçekleştirilen köklü mimari değişiklikler ve bunların mühendislik gerekçeleri aşağıda maddeler halinde sunulmuştur:

- Çift Bilgisayarlı Dağıtık Kontrol Mimarisine Geçiş: İlk tasarım aşamasında, sanal gerçeklik (VR) simülasyonu (Unity 3D) ile gerçek zamanlı görüntü işleme ve donanım takip süreçlerinin tek bir bilgisayar platformu üzerinden yürütülmesi planlanmıştır. Ancak yapılan testlerde, Unity 3D oyun motorunun ihtiyaç duyduğu yüksek grafik işleme yükü ile YOLOv8 tabanlı nesne algılama algoritmasının yarattığı anlık CPU/GPU yükünün aynı sistemde koşturulmasının, VR simülasyonunda kırılmalara (frame-drop) ve gecikmelere yol açtığı gözlemlenmiştir. Bu durumdan kurtulmak için sistem mimarisi bağımsız bir VR İstasyonu (Master) ve robot sahasında konumlandırılan bir Yerel İzleme İstasyonu (Slave) olmak üzere iki bağımsız bilgisayara bölünmüştür.
- Kablosuz Teleoperasyon Altyapısının (XBee) Entegre Edilmesi: Dağıtık mimariye geçilmesiyle birlikte, bilgisayarlar arasındaki veri bağının fiziksel kablolarla kurulması, projenin "uzaktan yönetilebilir (teleoperasyon) medikal platform" vizyonunu ve fiziksel bağımsızlığını kısıtlamıştır. Gerçek ameliyathane veya lojistik depo senaryolarındaki "izole operatör kabini" mantığını tam olarak simüle edebilmek adına, iki istasyon arasına IEEE 802.15.4 standardında çalışan, düşük gecikmeli ve endüstriyel kararlılığa sahip XBee kablosuz haberleşme modülleri dahil edilmiştir.
- Arduino Mega Ana Kontrolörü ve Çoklu İşlemci Ayrımı: İlk elektronik tasarım taslaklarında tüm sistem bileşenlerinin tek bir mikrodenetleyici (ESP32) üzerinden yönetilmesi düşünülmüştür. Ancak final aşamasında, adımlı motorların mikrosaniye hassasiyetinde adım (step) sinyallerine ihtiyaç duyması ve aynı anda yüksek veri yoğunluklu seri iletişim (UART) hatlarının dinlenmesi gerekliliği, tek bir işlemcinin zamanlama hatası yapmasına ve motorlarda titremelere yol açmıştır. Bu mühendislik problemini çözmek amacıyla, motor sürme ve donanım yönetimi görevleri Arduino Mega ana kontrolörüne devredilmiş; ESP32 ise sadece kendi üzerindeki kamera ve Grove Vision AI donanımından gelen YOLOv8 yapay zekâ veri akışını yöneten bağımsız bir görüntü işleme co-processor'ü (yardımcı işlemci) olarak konumlandırılmıştır.

Yapılan bu optimizasyonlar sonucunda platform; ilk dönem tasarlanan basit bir robotik düzenek yapısından sıyrılarak, endüstriyel standartlarda çalışan, veri paket kaybı engellenmiş ve asenkron süreçleri başarıyla yönetebilen kararlı bir Dağıtık Kontrol Sistemi haline getirilmiştir.

### 2.2. Sanal Katman: Unity ve VR Çalışmaları

### 2.2.1. Simülasyon tabanlı robotik kontrol ve dijital ikiz mimarisi

Bu projenin temel tasarım felsefesi, sanal ortam (VR) ile fiziksel dünya (Robotik Sistem) arasında çift yönlü bir iletişim köprüsü kurmaktır. Tasarlanan sistemde Unity ortamı, pasif bir görselleştirme aracı değil, fiziksel robotun karar mekanizmasını tetikleyen bir “Kontrol Arayüzü” olarak kurgulanmıştır. Dijital İkiz yaklaşımımız şu senaryo üzerine inşa edilmiştir.

- Sanal Karar: Kullanıcı VR ortamında, karmaşık cerrahi set içerisinden spesifik bir alet (Örn: Neşter) seçer.
- Veri İletimi: Bu seçim verisi, kablosuz haberleşme protokolleri (UDP/Wi-Fi) üzerinden fiziksel dünyaya aktarılır.
- Fiziksel Eylem: ROS tabanlı robot kol, gelen veriyi işleyerek gerçek dünyadaki aletler arasından görüntü işleme teknikleri ile doğru eşleşmeyi bulur ve o aleti tutar. Bu yapı sayesinde simülasyon, cerrahi eğitimin ötesine geçerek, tele-operasyon ve uzaktan cerrahi (telesurgery) uygulamaları için bir prototip niteliği taşımaktadır.

### 2.2.2. Unity oyun motoru ve fizik altyapısı

Simülasyonun geliştirilmesinde, sunduğu gelişmiş fizik motoru (PhysX) ve yüksek render kabiliyeti nedeniyle Unity 6 tercih edilmiştir. Unity’nin tercih edilmesindeki temel etkenler şunlardır:

- HDRP (High Definition Render Pipeline): Fotogerçekçi görüntülerin işlenmesinde yüksek performans sağlaması.
- NavMesh (Navigasyon Ağı): Karakter hareketlerinin belirlenen sınırlar içinde kontrol edilebilmesi.
- Fizik Etkileşimi: Cerrahi aletlerin yer çekimi, çarpışma (collision) ve sürtünme gibi fiziksel kurallara uygun davranmasının sağlanması.

### 2.2.3. Cerrahi eğitimde paradigma değişimi

Bu modelde öğrenciler, ameliyathane ortamında süreci gözlemleyerek ve zamanla dahil olarak yetkinlik kazanırlar. Ancak günümüzde, gelişen teknoloji ile hasta güvenliği ve eğitimde eşitlik gibi konular giderek önem kazanmıştır. Bu bağlamda geleneksel model, ihtiyaçları karşılamada yetersiz kalmaktadır. Öğrencilerin az sayıda katılabildiği ameliyatlarda sadece pasif birer gözlemci olarak kalmaları cerrahi yetkinliğin kazanılma sürecini uzatmaktadır [11].

Bu bağlamda projemiz, literatürde “Gözlemden Katılıma Geçiş” olarak tanımlanan yeni bir eğitim modelini temel almaktadır. Geliştirdiğimiz simülasyon
ortamı, cerrah | adaylarını | pasif | birer | gözlemci | olmaktan | çıkarıp
“VolumetricOR” (Hacimsel Ameliyathane) konsepti içerisinde aktif karar verici bireylere dönüştürmeyi hedeflemektedir. Bu yaklaşım; öğrencilerin sadece cerrahi aletleri tanımalarını değil, aynı zamanda ameliyathane içerisindeki mekânsal farkındalığı yaşayarak öğrenmelerini, tekrarlanabilir cerrahi senaryolar sayesinde hata yapabilmelerini, hatalarından ders çıkarabilmelerini sağlar.

### 2.2.4. VolumetricOR ve fotogrametrik rekonstrüksiyon teknolojisi

Proje kapsamında kullanılan sanal ameliyathane ortamı, yapay 3D modelleme teknikleri ile sıfırdan çizilmiş bir ortam değildir. Gerçekçiliği kullanıcıya en üst düzeyde hissettirmek amacıyla, Berlin Charité Üniversitesi Hastanesi’nin gerçek bir ameliyathanesinin görüntü tabanlı 3B modelleme ile oluşturulmuş bir ortamdır [6][10][12]. Bu teknik altyapı şu üç temel bileşenden oluşmaktadır:

### 1. Fotogrametrik Tarama: Gerçek ameliyathanenin yüzlerce farklı

açıdan çekilmiş yüksek çözünürlüklü fotoğrafları Metashape gibi yazılımlarla işlenerek 3 boyutlu bir nokta kümesine dönüştürülmüştür.

### 2. Texture Mapping: Elde edilen 3B geometri, fotoğraflardan alınan renk

ve doku bilgileri ile bir araya getirilerek gerçekçi bir görünüm elde edilmiştir.

3. Hacimsel Derinlik: Standart 360-derece videolardan farklı olarak, oluşturulan bu hacimsel ortam kullanıcının sadece etrafına rotasyonel olarak bakmasına değil, ortam içerisinde fiziksel olarak yürümesine, nesnelere yaklaşmasına olanak sağlar.

Bu sayede, simülasyonumuzdaki kullanıcı, cerrahi bir aleti tutmak için masaya yaklaştığında sanal ortamdaki derinlik algısı gerçek dünyadakiyle birebir örtüşmektedir. Bu, robotik cerrahi sistemimizi yönetecek kullanıcının gerçeklik algısını en yüksek düzeyde hissetmesi ve uzaktaki robotun çalışma alanını doğru algılaması için kritik bir gerekliliktir.

### 2.2.5. İşitsel atmosfer tasarımı ve psikolojik gerçekçilik

Bu simülasyonun başarısı sadece görsel kalitesiyle değil, kullanıcıya hissettirdiği “orada olma” duygusuyla ölçülür. Literatürdeki çalışmalar, görsel gerçekçiliğin yanı sıra işitsel ipuçlarının da cerrahi performansı etkilediğini göstermektedir. Gerçek bir ameliyathane, kütüphane gibi sessiz bir ortam değildir; monitör sesleri, ventilatör uğultusu ve ekip içi konuşmaların olduğu bir ortamdır [10][12].

Projemizde bu psikolojik gerçekçiliği sağlamak adına Unity ortamına 3D uzamsal ses teknolojisi entegre edilmiştir. Arka planda sürekli olarak çalan ritmik kalp atış monitörü sesleri, ventilatör cihazının mekanik sesi ve düşük desibelli ameliyathane ortam gürültüsü simülasyona eklenmiştir. Bu işitsel katmanın sisteme eklenmesinin iki temel amacı vardır:

### 1. Duyusal Duyarsızlaştırma: Cerrah adaylarının stres yaratan sesler

altında dahi odaklanma becerisini geliştirmek.

### 2. Gerçekçilik Hissini Artırma: Simülasyon kullanıcısının kendisini

ameliyathanenin tamamıyla içinde hissetmesini sağlamak.

### 2.2.6. PC tabanlı kontrol

Simülasyonun fizik motorunu ve nesne etkileşim algoritmalarını test etme amacı ile, sistem öncelikle PC tabanlı bir kontrol mimarisi üzerine inşa edilmiştir. Kullanıcı, ok tuşları ile ameliyathane içinde hareket ederken, farenin sağ tuşuna basılı tutarak bakış açısını değiştirmekte ve sol tuşuna tıklayarak ise cerrahi aletleri seçmektedir.

VR donanımlarının kurulum ve kalibrasyon süreçlerinin zaman alıcı olması sebebi ile oyun motoru olan Unity’i tanımak, backend ve debugging süreçlerini hızlandırmak ve sistemin kararlılığını garanti altına alma amacı ile ilk aşamada PC tabanlı bir kontrol mimarisi inşa edilmiştir.

### 2.2.7. Giriş ekranı ve volumetrik ameliyathane ortamının kurulması

Kullanıcı deneyimini arttırmak ve kolaylaştırmak için simülasyonumuzun ilk açılışında giriş ekranı gelmektedir. Şekil 5’te verilen giriş ekranı “Simülasyonu Başlat” ve “Çıkış Yap” butonlarını içermektedir. Berlin Charité Hastanesi'nden elde edilen ham mesh verileri ve dokular (textures), Unity ortamına aktarılmıştır. Ortamın gerçekçiliğini artırmak adına Unity’nin “Occlusion Culling” (Görünmeyen yüzeylerin çizilmemesi) ve “GPU Resident Drawer” teknolojileri kullanılarak performans optimizasyonu sağlanmıştır. Bu sayede, işlemci (CPU) üzerindeki çizim yükü ekran kartına (GPU) aktarılarak yaklaşık 6 × 10⁵ poligonluk yüksek detaylı sahne, 90 FPS (kare/saniye) üzerinde stabil şekilde çalıştırılmıştır. Ayrıca ameliyathane atmosferini desteklemek amacı ile monitör, ventilatör sesleri 3D uzamsal ses olarak sahneye yerleştirilmiştir [11][14].

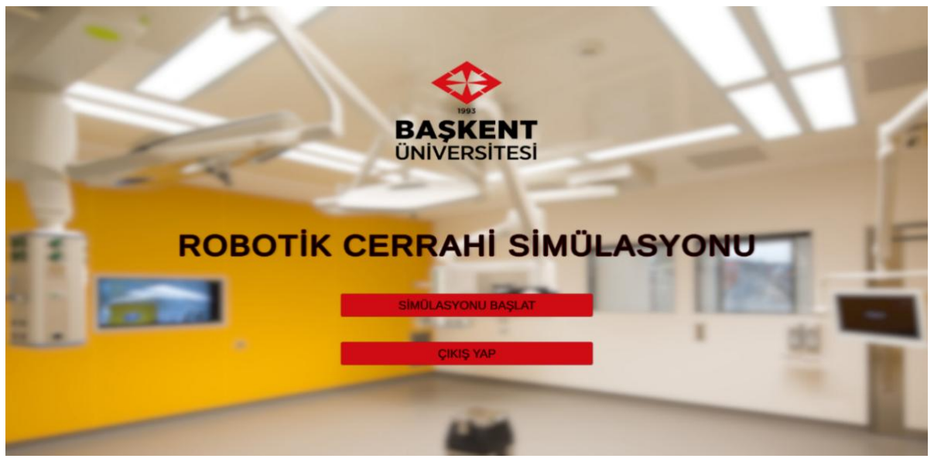
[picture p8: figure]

Şekil 5 Simülasyon Giriş Ekranı

Şekil 6'da proje kapsamında geliştirilen sanal ameliyathane ortamı gösterilmektedir. Ortam, Berlin Charité Hastanesi'nden elde edilen görüntüler kullanılarak gerçekleştirilen görüntü tabanlı 3B modelleme çalışmalarıyla oluşturulmuştur. Ameliyat sırasında kullanılan steril ekipmanların bulunduğu cerrahi masalar sahneye yerleştirilmiş olup, bu masalar çok sayıda cerrahi aletin düzenli biçimde konumlandırılmasına olanak sağlayan geniş çalışma yüzeylerine sahiptir. Operasyonel gerçekçiliği artırmak amacıyla, NMY Mixed-Reality Communication GmbH tarafından modellenen yüksek gerçeklik seviyesine sahip cerrahi alet koleksiyonu kullanılmıştır. Neşter, makas ve klemp gibi temel cerrahi araçlar fizik motoruna entegre edilerek kullanıcı etkileşimine uygun hale getirilmiştir.

Cerrahi eğitim senaryolarının oluşturulabilmesi amacıyla fotometrik tarama yöntemiyle elde edilmiş gerçekçi bir hasta mankeni ameliyat masasına
konumlandırılmıştır. Ayrıca | kullanıcının sanal ortamdaki | varlık | hissini
güçlendirmek amacıyla, sanal eli temsil eden ve Autodesk Maya ile Substance

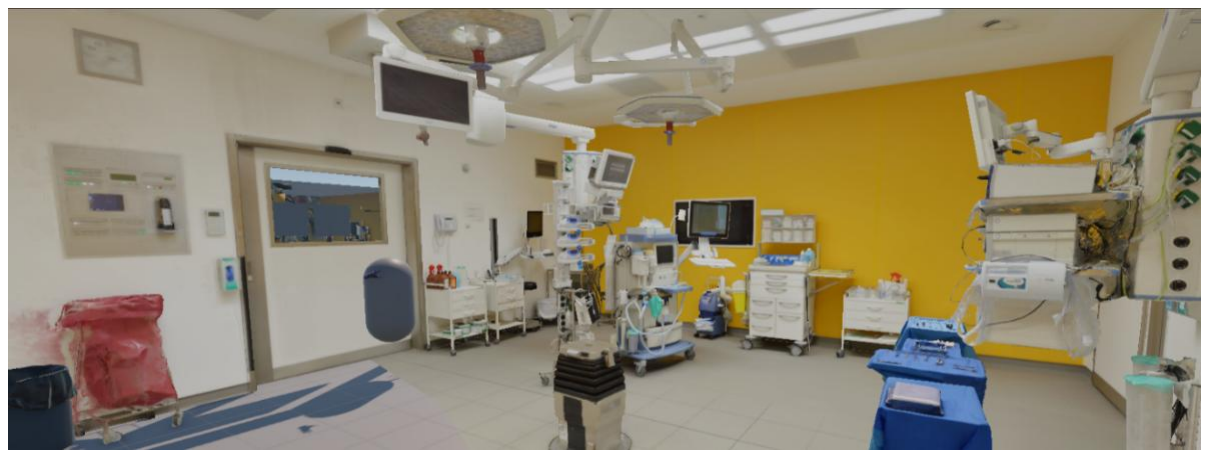
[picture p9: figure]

Şekil 6 Ameliyathane Ortamı

Painter yazılımları kullanılarak modellenen yüksek detaylı cerrahi eldivenli el modeli sisteme entegre edilmiştir. Model üzerinde kıvrım, dikiş ve yüzey dokusu gibi ayrıntılar korunarak gerçekçi bir görünüm elde edilmiştir.

Sahnedeki yüksek poligonlu modeller ve detaylı çevresel unsurlar nedeniyle oluşabilecek performans kayıplarını önlemek amacıyla asenkron yükleme mimarisi kullanılmıştır. Bu yaklaşımda sahne yükleme işlemleri arka planda ayrı bir iş parçacığında (thread) yürütülürken kullanıcıya bilgilendirici bir yükleme ekranı sunulmakta, böylece uygulamanın donması veya kullanıcı deneyiminin kesintiye uğraması engellenmektedir. [12] [13].

### 2.2.8. Kullanıcı navigasyonu ve kamera kontrol sistemi

VolumetricOR (Hacimsel Ameliyathane) konseptinde, kullanıcının sanal ameliyathanede sadece bir kamera gibi süzülmesi değil, bir cerrah gibi hareket etmesi istenir. Bu amaçla geliştirilen DoktorHareket.cs algoritması, insan biyomekaniğini ve algısal konforunu temel alan üç katmanlı bir yapı üzerine kurulmuştur. Geliştirilen navigasyon sistemi, insan biyomekaniğine uygun kısıtlamalar ve vektörel hesaplamalar içermektedir.

- Vektörel Hareket Hesabı

Kullanıcının hareketi, kameranın o anki bakış vektörüne göre dinamik olarak hesaplanmaktadır. Ancak cerrahi simülasyonlarda "uçma hissini" engellemek ve zemin temasını korumak adına CharacterController bileşeni üzerinden yapay bir yer çekimi kuvveti uygulanmıştır.

- Bakış Açısı Kısıtlaması

Gerçekçi bir insan anatomisi simülasyonu için kamera rotasyonuna matematiksel sınırlar getirilmiştir. Cerrahi masadaki aletlerin detaylı incelenebilmesi için sisteme bir eğilme mekaniği entegre edilmiştir. Ham fare verisinin doğrudan kameraya aktarılması, VR ve simülasyon ortamlarında titreme sorununu önlemek amacıyla, fare girdileri (Lineer İnterpolasyon fonksiyonu ile işlenerek, anlık değişimler yerine zamanla sönümlenen yumuşak bir bakış hareketi elde edilmiştir.

- İmleç Yönetimi

Simülasyon başlatıldığında farenin sağ tuşuna basarak kamera aşısını değiştirirken fare imleci ekranda gizlenmekte, ancak sağ tuşu serbest bırakıp aletlerin üzerinde gezinirken tekrar ekrana gelmektedir.

### 2.2.9. Nesne tespiti ve fizik tabanlı etkileşim algoritması

Simülasyon ortamında cerrah adaylarının sanal aletlerle kurduğu etkileşimin kararlılığı, sistemin kullanılabilirliği açısından kritik öneme sahiptir. Bu amaçla geliştirilen AletTutucu.cs sınıfı ile özelleştirilmiş bir tutma ve bırakma algoritması tasarlanmıştır.

- Işın İzleme (Raycasting) ile Hassas Tespit

Sistemin işlemci yükünü optimize etmek amacıyla, sanal kameranın merkezinden ileriye doğru bir ışın (Ray) gönderilmektedir. Bu ışın, tüm sahneyi taramak yerine sadece LayerMask yöntemiyle filtrelenmiş “Aletler” katmanındaki objeleri hedef almaktadır. Bu yöntem, yanlış objelerin seçilmesini algoritmik olarak engeller. Nesne seçimi yapıldığında, aletin aniden ele ışınlanması yerine, görsel akıcılığı korumak adına bir eşyordam yapısı kullanılmıştır. Şekil 7’de gösterilen simülatif el, eşya konumuna vektörel interpolasyonla süzülerek giderek eşyayı alır ve eşya ile birlikte başlangıç konumuna döner [16].

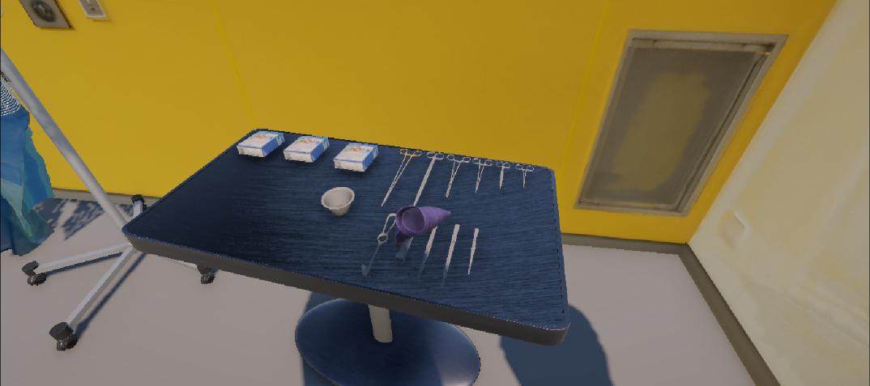
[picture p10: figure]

Şekil 7 Simülatif Elin Çalışması

### 2.2.10. Fizik motorunun oluşturulması ve işlenmesi

- Kinematik Kilitlenme

Şekil 8'de, kullanıcının cerrahi aletlerle etkileşim kurduğu tutma (grasping) mekanizması gösterilmektedir. Bir alet kullanıcı tarafından tutulduğunda, nesnenin Rigidbody bileşeni kinematik moda geçirilerek yer çekimi ve diğer fiziksel kuvvetlerden etkilenmesi engellenir. Böylece aletin kullanıcının sanal eli ile kararlı ve hassas bir şekilde eşleşmesi sağlanır. Nesne kinematik moda alındıktan sonra sistem, tutulan cerrahi aletin türünü analiz ederek önceden tanımlanmış tutuş pozisyonu ve açısını otomatik olarak uygular. Bu sayede her cerrahi alet, kullanım amacına uygun ergonomik bir kavrama şekliyle elde tutulur ve gerçekçi kullanıcı etkileşimi desteklenir.

- Çarpışma İzolasyonu

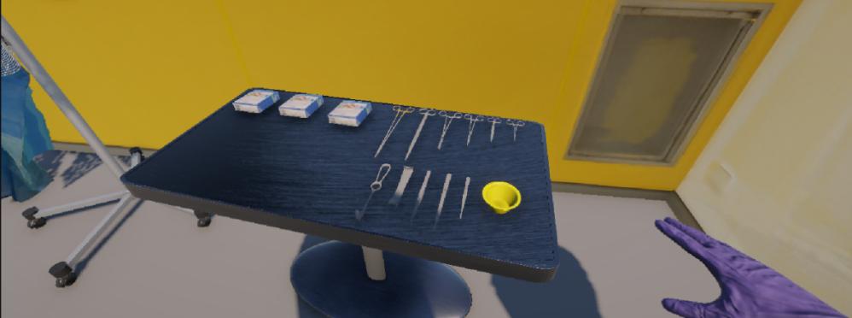
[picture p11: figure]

Şekil 8 Simülasyon Ortamında Kinematik Kitlenme

Alet ele alındığında, kullanıcının sanal gövdesiyle çakışıp fiziksel hatalara yol açmaması için çarpışma algılayıcıları geçici olarak devre dışı bırakılır.

- Hiyerarşik Ebeveynleme

Şekil 9'da, Unity oyun motorunda kullanılan nesne ebeveynleme (parenting) mekanizması gösterilmektedir. Kullanıcı bir cerrahi aleti tuttuğunda, seçilen nesne yazılımsal olarak sanal el modelinin alt nesnesi (child object) olarak atanır. Bu sayede alet, elin konum ve yönelim bilgilerini gerçek zamanlı olarak takip ederek doğal bir tutma davranışı sergiler. Bırakma işlemi gerçekleştirildiğinde ise nesnenin ebeveyn ilişkisi kaldırılır, fizik motoru yeniden etkinleştirilir ve nesnenin yer çekimi ile diğer fiziksel etkilere tepki vererek doğal bir şekilde ortam içerisine düşmesi sağlanır.

Seçilen nesne, yazılımsal olarak sanal elin çocuğu olarak atanır. Bırakma işleminde ise tüm bu süreç tersine işler ve nesnenin doğal bir şekilde arzu edilen yere düşmesi sağlanır.

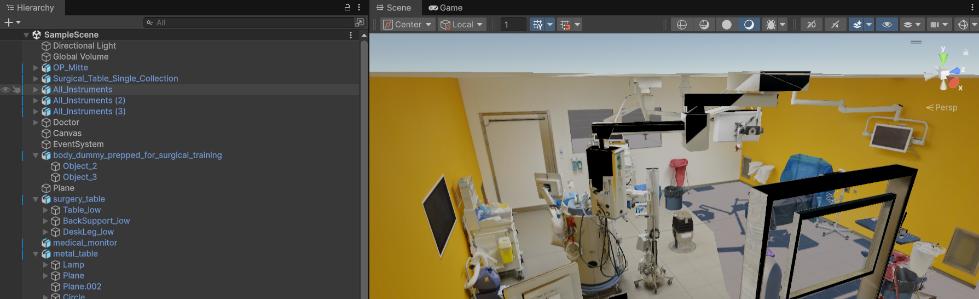
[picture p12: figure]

Şekil 9 Simülasyon Ortamında Kinematik Kitlenme

- Hata Toleransı ve Otonom Geri Kazanım

Sistemin sürdürülebilirliği için YereDusenAlet.cs fonksiyonu ile otonom bir denetleyici geliştirilmiştir. Bu algoritma, 'Zemin' etiketiyle temas eden aletleri tespit eder, 2 saniyelik bir bekleme süresinden sonra aletin fiziğini dondurur ve steril masadaki başlangıç koordinatlarına otomatik olarak geri ışınlar. Bu sayede VR deneyimi kesintiye uğramadan devam eder.

### 2.2.11. Biyomekanik hareket analizi ve doğrulama testleri

- Normal Durum Müdahalesinde Hız Analizi

Mevcut simülasyonda kullanıcı deneyimi odaklı olduğu için 1,8 m/s hıza ulaşırken; gerçek dünyada bir cerrah hızı 1,5 m/s’dir. Şekil 10’da verilen mavi simülasyon çizgisinde, hareketin 'Lineer' olduğu gözlemlenebilir, karakter anında hızlanıp anında durmaktadır, yeşil biyomekanik referans eğrisinde cerrahın yumuşak bir kalkış ve duruş sergilediğini gözlemlenir.

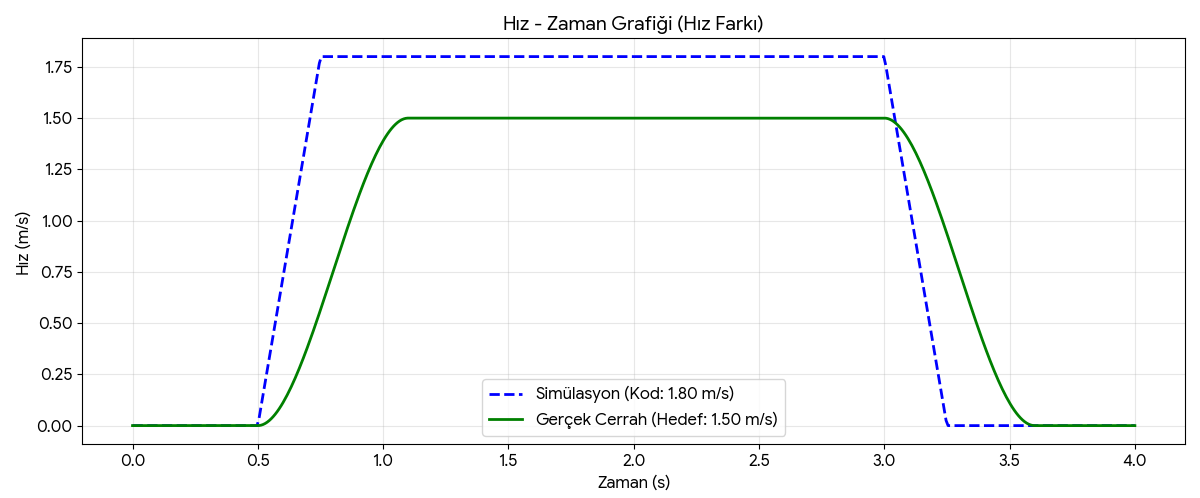
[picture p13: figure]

Şekil 10 Normal Müdahalede Hız-Zaman Grafiği

- Normal Durum Müdahalesinde İvme Analizi

Şekil 11’de verilen ivme zaman grafiğindeki kırmızı kesikli çizgiler, simülasyonun dijital tepkilerini göstermektedir. Tespit edilen 'diken'

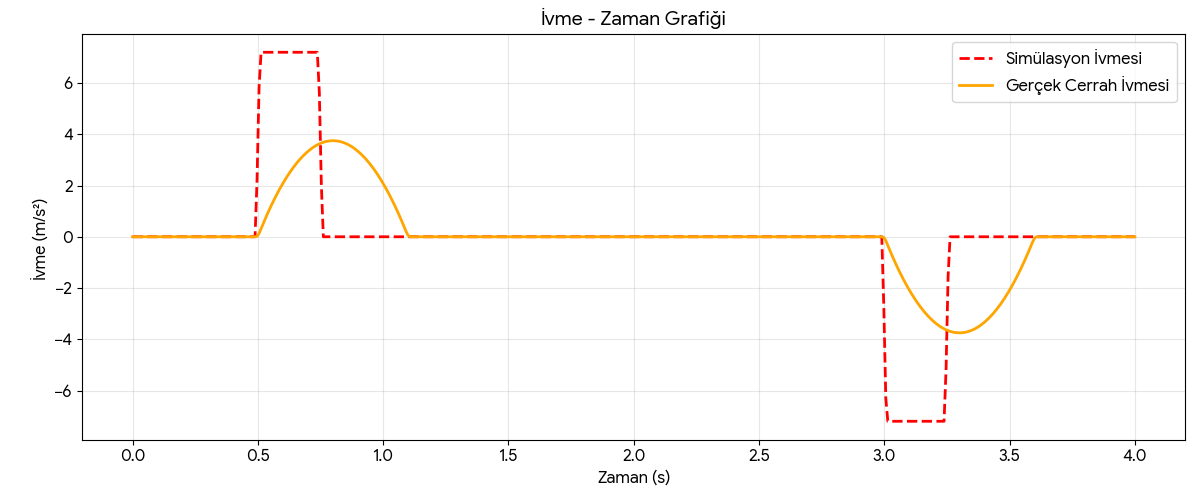
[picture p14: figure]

(spike) şeklindeki ani zıplamalar, karakterin fiziksel bir ağırlığı olmadığını, hareketin anlık başladığını işaret eder. Bu, gerçekçilikten uzaktır. Turuncu hat ise gerçek insan kas sistemini temsil eder. Cerrah harekete geçerken kuvveti zamana yayar (tepe şekli). Bu, ani sarsıntıları önler ve cerrahın el hassasiyetini korumasına yardımcı olur.

Şekil 11 Normal Müdahalede İvme-Zaman Grafiği

- Acil Durum Müdahalesinde Hız Analizi

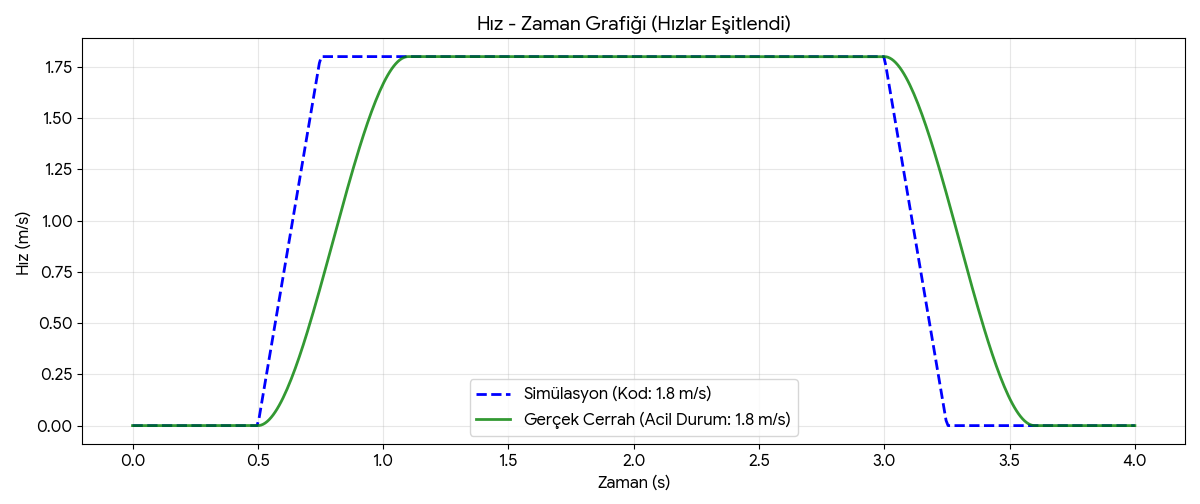
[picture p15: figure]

Şekil 12 Acil Müdahalede Hız-Zaman Grafiği

Şekil 12’de verilen hız zaman grafiğine bakıldığında, mavi kesikli çizgi (Simülasyon) ve yeşil düz çizgi (Gerçek Cerrah) aynı tepe noktasına ulaşmaktadır. Simülasyon grafiğindeki köşelerde hızlanmadan sabit hıza geçiş aniden, gerçekleşirken, gerçek cerrahın hareketini gösteren yeşil çizgide ise bu geçişler yumuşak birer kavis şeklindedir. İnsan vücudu, acil durumda bile fizik kuralları gereği eylemsizliğini yenmek için bu kavisi çizmek zorundadır.

- Acil Durum Müdahahesinde İvme Analizi

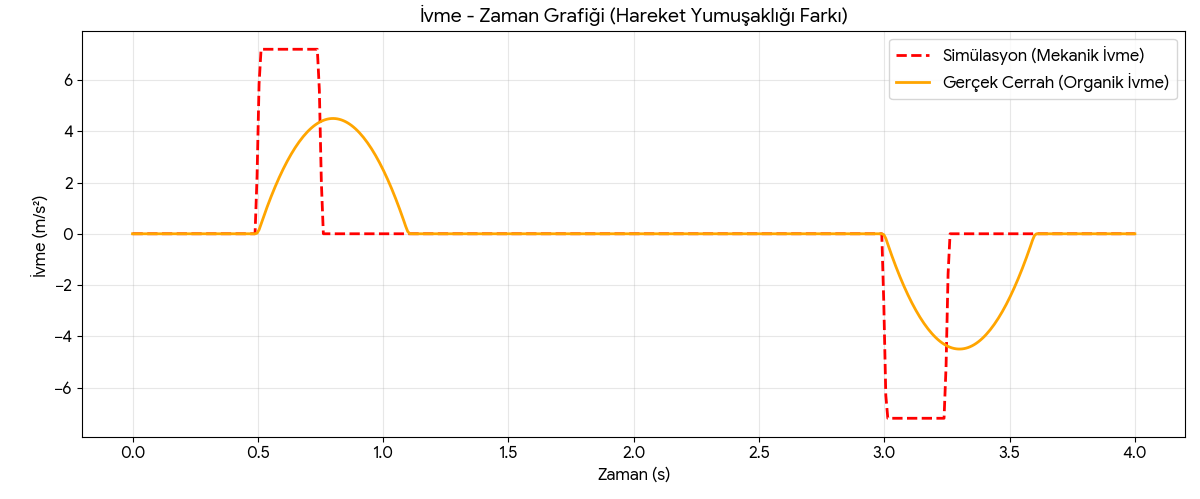
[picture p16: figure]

Şekil 13 Acil Müdahalede İvme-Zaman Grafiği

Şekil 13’te verilen ivme zaman grafiği hareket hissi farkının temel nedenini, yani uygulanan kuvveti göstermektedir. Dijital "Kare Dalga" (Kırmızı Çizgi), simülasyonda hareketi başlatmak için anında maksimum kuvvet uygulamakta, hız sabitlenince kuvveti anında sıfıra indirmektedir. Dijital dünyada mümkündür ama gerçek hayatta bu, sürekli sarsılmak gibi bir his vermektedir.

Analog "Tepe" (Turuncu Çizgi) Turuncu çizgi ise insan kaslarının çalışma prensibini göstermektedir. Acil durumda dahi kuvvet bir anda değil, bir 'tepe' oluşturacak şekilde kademeli olarak artar ve azalır. Bu, hareketin akıcı ve sarsıntısız olmasını sağlayan 'organik ivmelenme olarak adlandırılır.

### 2.2.12. Etkileşim zamanlaması ve reaksiyon analizi

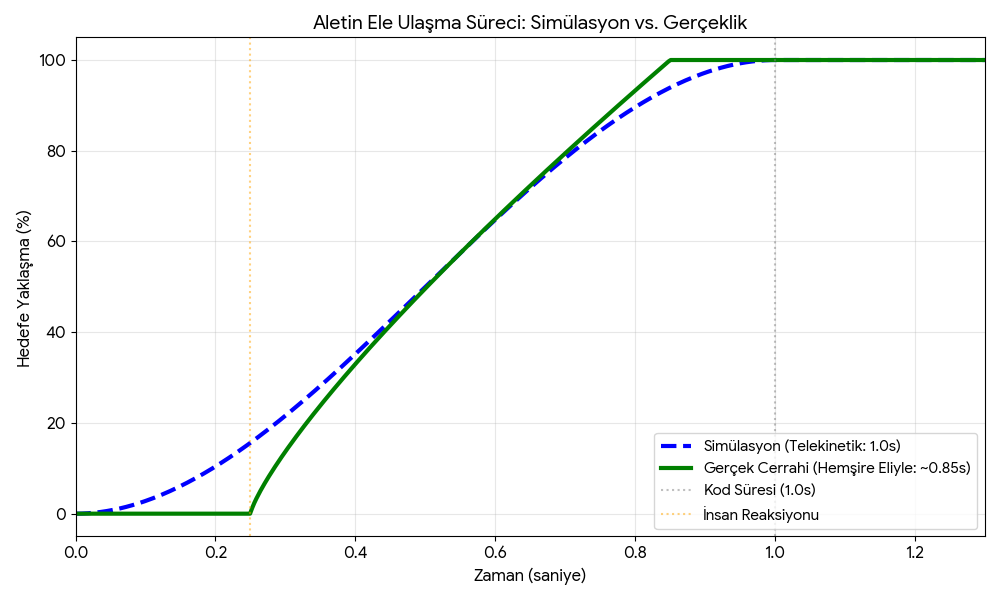
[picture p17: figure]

Şekil 14 Etkileşim Zamanlayıcısı Grafiği

Şekil 14’te verilen yeşil çizgi ise gerçek bir hemşirenin aleti cerraha uzattığı andır. Ölü Zaman (Reaksiyon) ise grafiğin başında (0.0- 0.25 sn arası) yeşil çizgi sıfırda kalmaktadır. Bu, cerrah 'Neşter' dediğinde hemşirenin bunu duyup aleti kavrayıp harekete geçmesi için gereken doğal insan reaksiyon süresidir. Reaksiyon sonrası (0.25 sn'den sonra), yeşil çizginin eğimi maviye göre çok daha diktir.

### 2.2.13. VR’a geçişin temel amacı

VR’a geçişin temel amacı, mevcut simülasyon yapısının yalnızca ekrandan takip edilen bir sahne olmaktan çıkarılarak kullanıcının doğrudan içinde yer aldığı etkileşimli bir eğitim ortamına dönüştürülmesidir. Bu kapsamda kullanıcı, ameliyathane ortamını baş hareketleriyle doğal biçimde inceleyebilmeli, fiziksel hareketlerini sanal ortama aktarabilmeli ve cerrahi aletlerle daha gerçekçi bir etkileşim kurabilmelidir.

Bu geçiş sürecinde hedeflenen başlıca kazanımlar aşağıda verilmiştir:

- Kamera kontrolünün mouse bağımlılığından çıkarılarak headset tracking sistemi üzerinden sağlanması.
- Klavye tabanlı hareket yapısı yerine XR locomotion bileşenlerinin kullanılması.
- Kullanıcının | fiziksel | yürüyüşünün | sahne | içindeki | hareketle
ilişkilendirilmesi.
- Controller tabanlı tutma, bırakma ve etkileşim mekanizmalarının oluşturulması.
- Cerrahi | aletlerin | yalnızca | kendilerine | ait | doğru | socket/yuvaya
yerleştirilebilmesi.
- Giriş ekranı, butonlar ve menüler gibi UI elemanlarının VR ortamında görünür ve tıklanabilir hale getirilmesi.
- SteamVR, OpenXR ve VIVE altyapıları aracılığıyla headset’in Unity ile doğru şekilde haberleşmesinin sağlanması.
- Proje değişikliklerinin GitHub Desktop üzerinden takım arkadaşlarına aktarılabilir ve sürdürülebilir hale getirilmesi.

Bu hedefler doğrultusunda proje mimarisinde yapılan temel dönüşüm, klasik Main Camera ve hareket scripti yaklaşımından XR Origin, XR locomotion ve headset tracking merkezli VR mimarisine geçilmesidir. Böylece simülasyon, yalnızca bilgisayar ekranında çalışan bir yazılım olmaktan çıkarılarak gerçek zamanlı takip, kullanıcı hareketi ve controller etkileşimi içeren daha bütünleşik bir VR eğitim platformuna dönüştürülmüştür.

### 2.2.14. Kullanılan altyapılar ve seçilme nedenleri

Projenin VR katmanında kullanılan altyapılar, cihaz uyumluluğu, geliştirme kolaylığı, modülerlik ve ileride yapılabilecek genişletmelere uygunluk kriterleri dikkate alınarak seçilmiştir. Bu kapsamda Unity Engine, OpenXR, SteamVR, VIVE Console, XR Interaction Toolkit ve Unity Input System birlikte kullanılmıştır.

- Unity Engine

Unity Engine, projenin ana geliştirme ortamı olarak kullanılmıştır.
Ameliyathane | sahnesinin | oluşturulması, | 3B | modellerin | sahneye
yerleştirilmesi, fizik sistemi, collider yapıları, scriptler, kullanıcı arayüzü ve VR entegrasyonu Unity üzerinden yönetilmiştir. Unity’nin tercih edilmesindeki temel neden, VR projeleri için geniş paket desteği sunması, XR Interaction Toolkit gibi hazır altyapılarla hızlı geliştirme olanağı sağlaması ve C# dili ile özel davranışların yazılmasına imkân vermesidir. Bu projede Unity yalnızca görsel sahneyi barındıran bir oyun motoru olarak değil, aynı zamanda simülasyon mantığını yöneten merkezi yazılım platformu olarak kullanılmıştır. Kamera kontrolü, kullanıcı hareketi, controller etkileşimi, cerrahi aletlerin socketlere yerleştirilmesi, giriş menüsü, sahne geçişleri ve XBee haberleşmesi gibi farklı bileşenler Unity sahnesi içinde bir araya getirilmiştir.
- OpenXR

OpenXR, VR cihazları ile oyun motoru arasında standart bir iletişim katmanı oluşturmak amacıyla kullanılmıştır. Farklı VR cihazlarının üreticiye özel SDK’lara bağımlı kalmadan Unity içinde çalışabilmesi, projenin donanım bağımsızlığını ve uzun vadeli sürdürülebilirliğini artırmaktadır. Bu projede OpenXR, Unity ile VR headset ve controller verileri arasında ara katman görevi üstlenmiştir.

OpenXR’ın tercih edilmesindeki temel gerekçe, cihaz bağımsız ve daha esnek bir XR altyapısı sunmasıdır. Proje HTC Vive cihazı ile geliştirilmiş olsa da OpenXR kullanımı, ilerleyen aşamalarda farklı OpenXR destekli cihazlara geçiş yapılmasını kolaylaştırmaktadır. Bu sayede sistem tek bir donanım markasına tamamen bağlı kalmadan geliştirilebilir bir yapıya sahip olmuştur [17].

- SteamVR

SteamVR, PC tabanlı VR sistemlerinde headset’in algılanması, controller verilerinin alınması, tracking sisteminin çalıştırılması ve Unity’den gelen görüntünün gözlüğe aktarılması için kullanılan runtime ortamıdır. Vive tabanlı kurulumlarda SteamVR, donanım ile Unity arasında çalışan temel çalıştırma katmanı olarak önemli bir rol üstlenmektedir.

İlk testlerde gözlükte yalnızca bilgisayar ekranının görünmesi, Unity sahnesinin gerçek VR render akışına bağlanmadığını göstermiştir. SteamVR ve OpenXR runtime ayarlarının düzenlenmesiyle Unity sahnesi gözlük içerisinde gerçek VR ortamı olarak görüntülenebilmiştir. Bu durum, VR projelerinde runtime seçimi ve ayarlarının yalnızca yardımcı bir işlem değil, sistemin çalışması için temel bir gereklilik olduğunu göstermektedir.

- VIVE Console

VIVE Console, HTC Vive cihazlarının bağlantı durumu ve bazı donanım ayarlarının kontrol edilmesi amacıyla kullanılmıştır. Headset’in bilgisayar tarafından tanınıp tanınmadığının görülmesi, cihaz durumunun kontrol edilmesi, görüntü ve performans ayarlarının izlenmesi gibi işlemler bu yazılım aracılığıyla desteklenmiştir.

VIVE Console’un tercih edilme nedeni, Vive cihazları için üretici tarafından sağlanan destek yazılımı olmasıdır. Özellikle headset bağlantısının doğrulanması, cihaz kaynaklı sorunların ayırt edilmesi ve SteamVR ile donanım tarafındaki çalışma durumunun izlenmesi açısından proje sürecinde destekleyici bir rol üstlenmiştir.

- XR Interaction Toolkit

XR Interaction Toolkit, Unity içerisinde VR ve AR etkileşimlerinin component tabanlı olarak kurulmasını sağlayan temel paketlerden biridir. Bu projede XR Origin, controller yapısı, interactor sistemleri, locomotion, snap turn, continuous turn, grab interactable ve socket interactor gibi birçok VR mekanizması bu paket üzerinden yapılandırılmıştır.

Bu toolkit’in seçilmesindeki temel neden, hazır ve modüler bir yapı sunmasıdır. Böylece alet tutma, bırakma, socket doğrulama ve UI etkileşimi gibi davranışların tamamının sıfırdan yazılması yerine Unity’nin XR için geliştirilmiş standart component’leri kullanılmıştır. Bu yaklaşım hem geliştirme süresini azaltmış hem de sistemin daha okunabilir ve yönetilebilir bir mimariye sahip olmasını sağlamıştır.

- Unity Input System

Unity Input System, XR controller inputlarının yönetilmesi amacıyla kullanılmıştır. VR ortamında input kaynakları yalnızca klavye veya mouse ile sınırlı değildir; controller grip, trigger, joystick, pose ve UI inputları gibi farklı veri tipleri bulunmaktadır. Bu nedenle klasik input sistemi yerine XR ile uyumlu action-based input yapısı tercih edilmiştir.

Projede locomotion ve UI etkileşimlerinde kullanılan controller girişleri, XRI action assetleri üzerinden sisteme bağlanmıştır. Fiziksel yürüyüşün öncelikli olarak kullanılmak istendiği durumlarda joystick hareketi sınırlandırılabilse de Input System, controller, menü ve etkileşim mekanizmalarının sağlıklı şekilde çalışması için temel bileşenlerden biri olarak korunmuştur.

### 2.2.15. XR Origin yapısı ve projedeki önemi

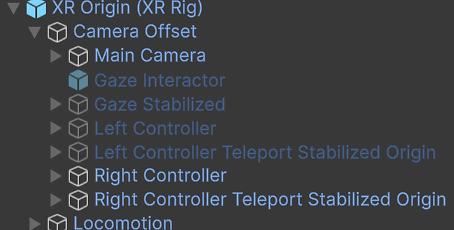
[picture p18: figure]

Şekil 15 XR Origin Yapısı

VR geçişinde kullanılan en kritik yapı XR Origin objesidir. Bilgisayar tabanlı simülasyonlarda oyuncu yapısı genellikle bir kamera ve bu kamerayı hareket ettiren scriptlerden oluşmaktadır. VR ortamında ise kullanıcıyı temsil eden ana yapı XR Origin’dir. Bu yapı, kullanıcının sanal dünyadaki kök objesi olarak görev yapar ve kamera, controller, etkileşim ve locomotion sistemlerini kendi altında toplar.

XR Origin yapısı içerisinde Şekil 15’te de görüleceği üzere genel olarak Camera Offset, Main Camera, controller objeleri, gaze veya near-far interactor yapıları, locomotion bileşenleri ve Character Controller gibi alt sistemler bulunmaktadır. Bu hiyerarşi sayesinde headset verisi kameraya, controller verisi el objelerine ve hareket girdileri XR Origin’in ana gövdesine aktarılabilmektedir.

Bu yapıda Main Camera, kullanıcının headset’ini temsil etmektedir. Kullanıcı başını çevirdiğinde, eğildiğinde veya fiziksel konumunu değiştirdiğinde bu hareketler tracking verisi aracılığıyla Main Camera üzerine uygulanır. Bu nedenle VR ortamında Main Camera’nın rotation değerinin doğrudan script ile değiştirilmesi uygun değildir. Başlangıç yönü veya sahnedeki kullanıcı yönelimi ayarlanmak istendiğinde Main Camera yerine XR Origin’in Y ekseni dönüşünün düzenlenmesi daha doğru bir yaklaşımdır.

XR Origin’in projedeki temel işlevleri:

- Kullanıcının VR dünyasındaki ana konumunu belirlemek.
- Headset tracking verisini kamera yapısı ile ilişkilendirmek.
- Sol ve sağ controller objelerini aynı hiyerarşi altında yönetmek.

- Locomotion bileşenleri aracılığıyla kullanıcının sahne içinde hareketini sağlamak.
- Character Controller ile çarpışma ve fiziksel sınırları yönetmek.
- Fiziksel oda hareketi ile sanal ortam arasında bağlantı kurmak.
Bu nedenle XR Origin’in scale, rotation ve parent yapısının doğru ayarlanması kritik öneme sahiptir. Proje sürecinde XR Origin scale değerinin değiştirilmesi el modelinin ve controller hiyerarşisinin bozulmasına neden olmuştur. Bu gözlem sonucunda XR Origin ölçeği üzerinden hareket artırma yaklaşımı uygun bulunmamış, bunun yerine fiziksel hareketi yazılımsal bir çarpanla büyüten movement multiplier mantığı tercih edilmiştir.

### 2.2.16. Kamera sisteminin sanal gerçekliğe uyarlanması

Bilgisayar tabanlı ilk sistemde kamera, mouse hareketiyle kontrol edilmekteydi. VR geçişiyle birlikte bu yapı devre dışı bırakılmıştır. Bunun nedeni, VR ortamında kamera hareketinin kullanıcı baş hareketlerine bağlı olarak headset tracking sistemi tarafından otomatik biçimde yönetilmesidir. Bu projede kamera sistemi, XR Origin altında yer alan Main Camera üzerinden çalışmaktadır. Headset takıldığında kullanıcının baş yönelimi doğrudan kameraya yansımaktadır. Kullanıcı başını sağa çevirdiğinde kamera sağa dönmekte, yukarı baktığında kamera yukarı yönelmekte ve eğildiğinde kamera fiziksel harekete uygun olarak aşağı inmektedir. Bu nedenle kamera, klasik sistemde olduğu gibi script ile döndürülmemiş; tracking sisteminden gelen verinin doğrudan kamera transform’una uygulanması sağlanmıştır.

Başlangıç aşamasında kamera yüksekliğinin normalden düşük görünmesi gibi problemlerle karşılaşılmıştır. Bu tür sorunlar Tracking Origin Mode, Character Controller Height, Center Y, Camera Offset ve XR Device Simulator ayarlarının kontrol edilmesiyle değerlendirilmiştir. Room-scale VR kullanımı için Tracking Origin Mode = Floor yaklaşımı daha uygun görülmüştür. Bu ayar, zemin seviyesini referans alarak kullanıcının sanal ortamdaki yüksekliğini fiziksel ortamla daha uyumlu hale getirmektedir.

Kamera yönüyle ilgili bir diğer durum, Unity sahnesinde Main Camera rotation değerinin manuel olarak değiştirilmesine rağmen oyun başlatıldığında bu değerin geçersiz kalmasıdır. Bunun nedeni, VR çalıştığında kameranın headset tracking tarafından güncellenmesidir. Bu nedenle başlangıç yönünü düzenlemek için Main Camera yerine XR Origin’in Y ekseni rotation değeri değiştirilmiştir. Bu yöntem, kullanıcının sahneye hangi yöne bakacak şekilde başlayacağını daha doğru ve kararlı biçimde yönetmeyi sağlamıştır.

### 2.2.17. Hareket sisteminin sanal gerçekliğe geçirilmesi

Başlangıçta | kullanıcı | hareketi | Input.GetAxis("Horizontal") | ve
Input.GetAxis("Vertical") gibi klasik klavye eksenleriyle sağlanmaktaydı. Bu yaklaşım bilgisayar tabanlı bir simülasyon için yeterli olsa da VR kullanımı için uygun değildir. VR ortamında hareket kaynağı joystick, headset tracking, fiziksel yürüyüş, grab move veya teleport gibi farklı yöntemlerle sağlanabilmektedir.
Bu nedenle hareket sistemi XR Interaction Toolkit locomotion yapısına geçirilmiştir. Locomotion sistemi altında Move, Turn, Grab Move, Teleportation, Climb, Gravity ve Jump gibi farklı alt bileşenler incelenmiştir. Hareket tarafında Dynamic Move Provider, dönüş tarafında ise Snap Turn Provider ve Continuous Turn Provider yapıları kullanılmış veya değerlendirilmiştir.
- Dynamic Move Provider

Dynamic Move Provider, controller inputlarına bağlı olarak XR Origin’i hareket ettiren temel bileşendir. Forward Source olarak Main Camera kullanıldığında, kullanıcının baktığı yön ileri hareket yönü olarak kabul edilir. Bu yaklaşım VR kullanıcı deneyimi açısından daha doğal bir hareket algısı sağlamaktadır. Örneğin kullanıcı ameliyat masasına doğru bakarken ileri hareket verdiğinde, sistem kullanıcıyı sahne içinde aynı yöne doğru ilerletmektedir.

- Snap Turn

Snap Turn, joystick sağa veya sola itildiğinde kullanıcının belirli bir açıyla anlık olarak dönmesini sağlar. Projede bu dönüş açısı 45 derece olarak ele alınmıştır. Snap Turn yapısının tercih edilmesindeki temel neden kullanıcı konforudur. VR ortamında sürekli ve yumuşak dönüş bazı kullanıcılarda baş dönmesi veya mide bulantısı oluşturabildiği için kesikli dönüş yapısı daha güvenli bir başlangıç seçeneği sunmaktadır.

- Continuous Turn

Continuous Turn, kullanıcının joystick’i sağa veya sola basılı tutmasıyla yumuşak dönüş yapılmasını sağlayan sistemdir. Projede Snap Turn ve
Continuous | Turn | yapılarının | birlikte | bulunduğu | durumlar
değerlendirilmiştir. Ancak iki dönüş sisteminin aynı anda aktif olması bazı kontrol çakışmalarına yol açabileceği için, eğitim simülasyonu bağlamında kullanıcı konforu dikkate alınarak öncelikli seçeneğin Snap Turn olması daha uygun görülmüştür.
- Fiziksel Yürüyüş

Projede joystick hareketinden farklı olarak, kullanıcının gerçek hayatta yürüyerek simülasyon içinde ilerlemesi de hedeflenmiştir. Bu yapı için headset tracking verisinin kullanılması gerekmektedir. Kullanıcı fiziksel olarak ileri yürüdüğünde Main Camera’nın XR Origin içindeki local pozisyonu değişmekte ve bu değişim sanal ortama aktarılabilmektedir.

Gerçek odadaki yürüme alanı sınırlı olduğu için fiziksel yürüyüşün simülasyondaki karşılığı ilk aşamada düşük kalmıştır. XR Origin scale değerini artırmak bu hareketi büyütmek için denenmiş olsa da bu yöntem el modeli ve controller hiyerarşisinde bozulmaya neden olmuştur. Bu nedenle XR Origin scale değerinin 1,1,1 olarak korunması gerektiği görülmüştür. Daha doğru çözüm, headset’in local pozisyon değişimini okuyarak XR Origin’e ek hareket uygulayan movement multiplier yapısının kullanılmasıdır.

Bu yaklaşım sayesinde kullanıcının gerçek ortamda kısa mesafeli
yürüyüşü | sanal | ortamda | daha | belirgin | bir | ilerlemeye
dönüştürülebilmektedir. Ancak bu sistemde yön hizalamasının doğru yapılması gerekmektedir. XR Origin yönü, fiziksel tracking yönü ve kamera yönü arasında uyumsuzluk oluşursa kullanıcı ileri yürüdüğünde sahne içinde farklı bir yöne hareket edebilir. Bu durumda XR Origin rotation değerinin veya movement multiplier içinde kullanılan yaw correction değerinin düzenlenmesi gerekir.

### 2.2.18. Controller ve etkileşim sistemi

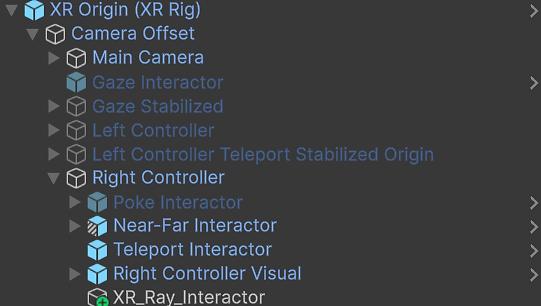
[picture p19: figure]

Şekil 16 XR Origin Controller Yapısı

Projede kontrolcü (controller) yapısı, Şekil 16’da görülen XR Origin alt yapısı kullanılarak kurgulanmıştır. Fiziksel donanım tarafında tek bir robotik kol bulunması ve sistemin tek el üzerinden komut alacak şekilde tasarlanması nedeniyle, Unity hiyerarşisinde optimizasyon yoluna gidilmiştir. Şekil 16’da yer alan Unity hiyerarşi (Hierarchy) penceresinde de görülebileceği üzere, sol kontrolcü nesnesi (Left Controller) devre dışı bırakılmış (disabled) ve tüm etkileşim mimarisi aktif olan sağ kontrolcü (Right Controller) objesi üzerinden yapılandırılmıştır.

Aktif olarak kullanılan sağ kontrolcü üzerinde Near-Far Interactor, Poke Interactor, Teleport Interactor ve XR Ray Interactor gibi interaktif bileşenler yer almaktadır. Bu bileşenlerden Near-Far Interactor, kullanıcının hem yakındaki nesnelerle doğrudan etkileşime girmesini hem de belirli bir mesafede yer alan nesneleri seçebilmesini sağlayan esnek bir yapı sunmaktadır.

Cerrahi aletlerle etkileşim süreci için XRGrabInteractable tabanlı bir sistem tercih edilmiştir. Bu yapı, bilgisayar tabanlı eski nesil mouse ile tıklama sistemlerinin yerini alarak kullanıcıya üç boyutlu serbestlik kazandırmıştır. Böylece kullanıcı,
cerrahi | aletleri | kontrolcü | yardımıyla | fiziksel | olarak | kavrayabilmekte,
taşıyabilmekte ve istediği alana bırakabilmektedir. Aletlerin üzerine gelindiğinde (hover durumu) kullanıcıya geri bildirim sağlamak amacıyla tetiklenen parlama (highlight) gibi görsel efektler ise XR eventleri aracılığıyla dinamik olarak yönetilmiştir.

Bu sistemin temel önemi, kullanıcıya gerçeğe yakın ve son derece doğal bir cerrahi simülasyon deneyimi sunmasıdır. Cerrahi aletlerin yalnızca ekrandaki pasif sanal objeler olarak kalmaması, doğrudan kullanıcının el hareketleriyle ilişkilendirilmesi ve fiziksel robotik çıktılara temel oluşturacak şekilde seçilebilir hale getirilmesi, simülasyonun eğitim değerini ve operasyonel gerçekçiliğini artırmaktadır. Bu sayede kullanıcı, ameliyathane ortamındaki alet yönetimi mantığını doğru bir etkileşim şemasıyla deneyimleyebilmektedir.

### 2.2.19. Socket sistemi ve aletlerin doğru yuvaya yerleştirilmesi

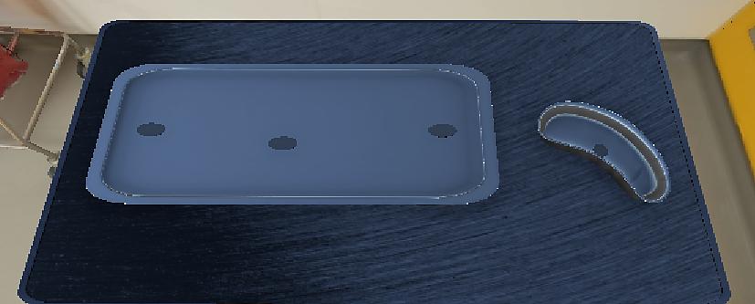
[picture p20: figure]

Şekil 17 Boş Soket Görünümü

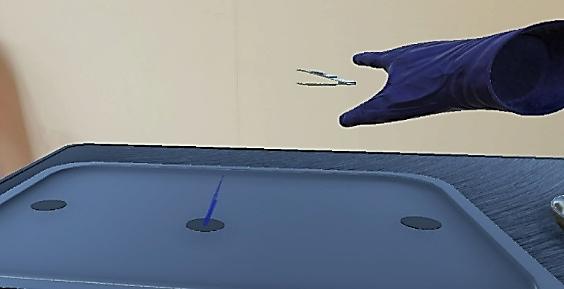
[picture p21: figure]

Şekil 18 Soket Geri Bildirim Mekanizması

Projede cerrahi aletlerin | sahnede | rastgele | konumlara bırakılmaması,
ameliyathane düzenine uygun olarak yalnızca kendilerine ait doğru socket/yuvaya yerleştirilebilmesi amaçlanmıştır. Bu amaç doğrultusunda XRSocketInteractor yapısı ve özel olarak geliştirilen KilitliCerrahiAlet script mantığı kullanılmıştır. Sahnede cerrahi aletlerin yerleştirileceği boş yuvaların genel düzeni ve konumu başlangıç senaryosu Şekil 17’de gösterilmiştir [17].

Bu sistemde her cerrahi alet için benzersiz bir hedef yuva tanımlanmıştır. Aletler yalnızca kendi hedef socket’i tarafından kabul edilmekte, yanlış socket’ler ilgili
aleti | seçmemekte | veya | yerleştirmemektedir. | Özellikle | medikal | eğitim
uygulamalarında cerrahi prosedürlerin ve alet yönetiminin hatasız öğrenilmesi büyük önem taşımaktadır. Yanlış bir aletin yanlış bir aşamada veya yuvada kullanılmasını engellemek adına sistem, kullanıcıya anlık görsel geri bildirim sunmaktadır. Şekil 18’de örneklendiği üzere; kullanıcı bir cerrahi aleti (örneğin penset) eline alıp yuvalara yaklaştırdığında, aletin yerleştirilmesi gereken doğru soketin üzerinde o alete ait lacivert bir parlama (hologram önizlemesi) belirir. Bu rehber niteliğindeki görsel mekanizma, kullanıcının doğru cerrahi protokolleri interaktif bir biçimde deneyimlemesini sağlamaktadır.
Alet | doğru | yuvaya | yerleştiğinde | kilitlenmekte, | Rigidbody | hareketleri
durdurulmakta, gravity (yerçekimi) devre dışı bırakılmakta ve aletin pozisyonu ile
rotasyonu | socket | attach | (bağlantı) | noktasına | göre | otomatik | olarak
düzenlenmektedir. Yerleştirme işlemi başarıyla tamamlandığında söz konusu lacivert görsel işaretler kapatılarak kullanıcıya sürecin bittiği bildirilmektedir.

Bu sistemin önemli avantajlarından biri, yanlış yere bırakılan aletlerin sahnede düşerek kaybolmasını veya fiziksel olarak ulaşılamayacak noktalara gitmesini engellemesidir. Kullanıcı aleti doğru socket dışında bir yere bırakmaya çalıştığında alet elde takip modunda kalmakta ve kullanıcının elinden tamamen ayrılmamaktadır. Bu yapı, simülasyonun hata toleransını artırmakta ve kullanıcının aleti yeniden doğru yuvaya yerleştirmesine imkân tanımaktadır. Socket sisteminde geliştirme aşamasında karşılaşılan önemli bir durumsal kısıt, VR headset ve kullanıcı konumunun fiziksel bir sınır gibi algılanması nedeniyle elin sokete yeterince yaklaştırılamaması olmuştur. Bu problemi çözmek için socket algılama alanının artırılması değerlendirilmiştir. Ancak soketlerin birbirine yakın konumlanması nedeniyle geleneksel Sphere Collider büyütme yaklaşımı çakışma (overlap) riski oluşturmuştur. Bu teknik engeli aşmak adına her socket için yönlü bir Box Collider veya child DetectionArea oluşturulması daha uygun bir çözüm olarak uygulanmıştır. Böylece algılama alanı her yöne simetrik biçimde genişletilmek yerine, kullanıcının elinin geldiği üst/ön yöne doğru kontrollü biçimde uzatılarak etkileşim kalitesi optimize edilmiştir [20].

### 2.2.20. Giriş ekranı ve VR UI sistemi

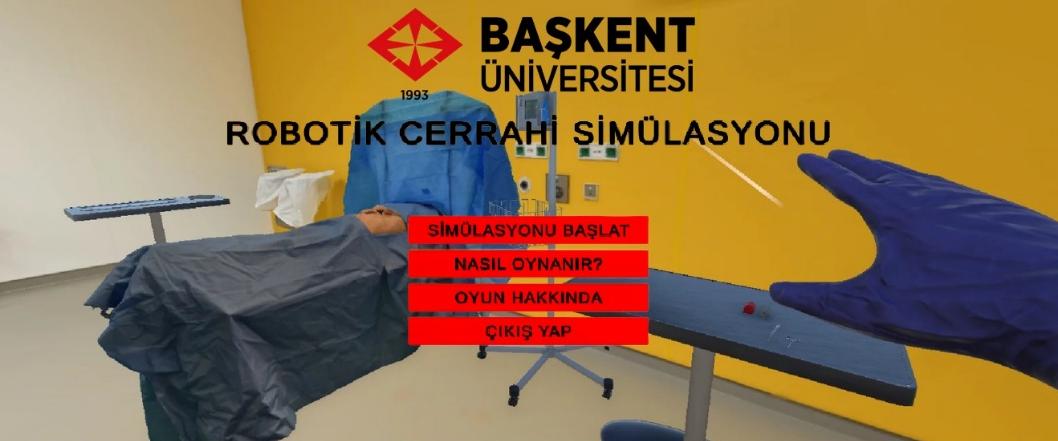
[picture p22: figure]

Şekil 19 VR Simülasyon Giriş Ekranı

Projede kullanıcıyı simülasyon öncesinde karşılaması için Şekil 19’daki giriş ekranı tasarlanmıştır. Bu ekran bilgisayar ekranında düzgün görünmesine rağmen VR gözlükte görünmeme, çok yakın görünme veya butonlara tıklanamama gibi sorunlar oluşturmuştur. Bu durumun temel nedeni, klasik UI sistemlerinin VR ortamında doğrudan aynı şekilde çalışmamasıdır.
Bilgisayar ekranı için hazırlanan Canvas yapıları genellikle Screen Space -Overlay veya Screen Space- Camera modunda çalışmaktadır. VR ortamında ise UI elemanlarının sahne içinde fiziksel bir yüzey gibi konumlandırılması daha uygun bir yaklaşımdır. Bu nedenle giriş ekranı için World Space Canvas yapısı tercih edilmiştir.

VR UI yapısının çalışabilmesi için uygulanan temel düzenlemeler aşağıda verilmiştir:

- Canvas, Main Camera’nın önüne yerleştirilmiştir.
- Canvas, VR_UI_Anchor adlı bir obje altında tutulmuştur.
- Anchor objesi Main Camera’nın child objesi olarak kullanılmıştır.
- Canvas scale değeri küçültülerek panelin VR ortamında doğal bir boyuta gelmesi sağlanmıştır.
- Panelin Canvas alanına tam oturması için anchor presetleri stretch olarak düzenlenmiştir.
- Butonların VR controller ile tıklanabilmesi için Tracked Device Graphic Raycaster ve XR UI Input Module gibi bileşenlerin gerekli olduğu belirlenmiştir.

Bu düzenlemeler sonucunda giriş panelinin yalnızca bilgisayar ekranında değil, VR gözlük içerisinde de görülebilir ve etkileşime açık hale gelmesi hedeflenmiştir. VR UI tasarımında panelin kullanıcıya olan mesafesi, boyutu ve scale değerleri dikkatli ayarlanmalıdır. Panelin çok yakın olması kullanıcı konforunu azaltmakta, çok büyük veya çok küçük olması ise okunabilirlik ve tıklanabilirlik açısından sorun oluşturabilmektedir.

### 2.2.21. Shader ve şeffaflık ayarları

Proje içerisinde bazı görsel elemanların tamamen şeffaf hale getirilmesi gerekmiştir. Bu durum özellikle UI elemanları, highlight yapıları veya sahnede görünmez kalması istenen yardımcı objeler için önemlidir. URP Lit shader kullanıldığında bir materyalin şeffaf olabilmesi için yalnızca renk değerindeki alpha kanalını düşürmek her zaman yeterli olmamaktadır. Materyalin Surface Type değerinin Transparent olarak ayarlanması gerekmektedir.
Bu nedenle şeffaflık için en uygun yöntem, materyalde Surface Type = Transparent seçeneğinin kullanılması ve Base Color alpha değerinin 0’a indirilmesidir. Bu işlem, objenin görsel olarak görünmez hale gelmesini sağlar. Ancak collider veya interaction davranışları görsel görünürlükten bağımsız olduğu için obje sahnede işlevsel olarak varlığını sürdürebilir.
Bu yapı, özellikle görünmez algılama alanları, yardımcı trigger bölgeleri veya kullanıcıya doğrudan gösterilmesi gerekmeyen etkileşim objeleri için kullanışlıdır.

Böylece sahne görsel olarak sade tutulurken, arka planda çalışan etkileşim ve fizik bileşenleri korunabilmektedir.

Şekil 20 XBee Hedef Mesaj Unity Konsolu

### 2.2.22. XBee haberleşmesi ve simülasyon- robot bağlantısı

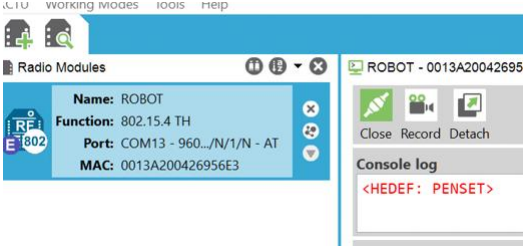
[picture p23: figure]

Şekil 21 XBee Alıcı XCTU Konsolu

Projede XBee haberleşmesi, Unity tabanlı VR simülasyonu ile harici bir robotik sistem arasında iki yönlü veri aktarımı sağlamak amacıyla entegre edilmiştir. Bu yapı, simülasyon içinde seçilen veya doğru socket’e yerleştirilen cerrahi alet bilgisinin dış sisteme anlık bir komut olarak gönderilmesini hedeflemektedir.

Sistemin çalışma prensibine dair örnek çıktılar ilgili görsellerde yer almaktadır. Unity tarafında çalışan XBee scripti, seri port üzerinden belirli formatlarda veri paketleri üretmektedir. Şekil 20’de görüldüğü üzere, simülasyonda bir etkileşim gerçekleştiğinde seçilen aletin adı alınarak bir hedef mesajı oluşturulmakta ve Unity ortamı "XBee Transmitter" (Verici) görevi görerek bu veriyi fiziksel ortama aktarmaktadır. Donanım tarafında ise, Digi firmasının XBee modüllerini yapılandırmak, test etmek ve izlemek amacıyla kullanılan resmi arayüz programı olan XCTU yazılımı açık bulunmaktadır. Şekil 21'deki XCTU konsol logunda (Console log) görüldüğü gibi, harici sistemdeki XBee modülü "Receiver" (Alıcı) görevi üstlenmekte ve Unity'den gönderilen <HEDEF: PENSET> verisini kayıpsız
bir | şekilde | fiziksel | robota | iletmektedir.

Bu sistemin önemi, VR simülasyonunun yalnızca görsel bir eğitim ortamı olarak kalmaması, fiziksel robotik mekanizmalarla gerçek zamanlı haberleşebilecek dinamik bir yapıya sahip olmasıdır. Ayrıca, geliştirilen yazılım mimarisinde XBee modülü takılı olmadığında sistemin hata vererek kapanmaması, bunun yerine otomatik olarak bir "test modu" uyarısı vermesi sağlanmıştır. Bu yaklaşım, hem gerçek donanım testlerinde hem de donanım bağlı değilken yürütülen yazılım geliştirme süreçlerinde esnek ve kararlı bir çalışma ortamı sunmaktadır [15].

### 2.2.23. Karşılaşılan başlıca problemler ve çözümleri

VR entegrasyonu sürecinde hem donanım bağlantısından hem de Unity içindeki XR yapılandırmasından kaynaklanan çeşitli problemlerle karşılaşılmıştır. Bu sorunlar, sistemin kararlı çalışabilmesi için adım adım incelenmiş ve uygun çözüm yaklaşımları geliştirilmiştir.

- Gözlükte yalnızca bilgisayar ekranının görünmesi

İlk aşamada gözlükte Unity sahnesinin kendisi yerine bilgisayar ekranı görüntülenmiştir. Bu durum, Unity’nin gerçek VR runtime akışına bağlanmadığını göstermektedir. SteamVR ve OpenXR ayarlarının kontrol edilmesi, doğru runtime yapısının seçilmesi ve XR Device Simulator gibi editör test araçlarının gerçek headset testinde devre dışı bırakılmasıyla bu sorun giderilmiştir.

- Fiziksel yürüyüşün simülasyonda sınırlı karşılık üretmesi

Kullanıcı gerçek ortamda yürüdüğünde simülasyon içinde beklenenden daha az ilerleme olduğu görülmüştür. XR Origin scale değerinin artırılması bu hareketi büyütmek için denenmiş, ancak bu işlem el modellerinde ve controller yapısında bozulmaya neden olmuştur. Bu nedenle fiziksel headset delta hareketini yazılımsal bir çarpanla artıran movement multiplier yaklaşımı daha uygun çözüm olarak değerlendirilmiştir.

- İleri hareket sırasında farklı yöne gidilmesi

Kullanıcı fiziksel olarak ileri yürüdüğünde simülasyonda farklı bir yöne hareket oluşması, fiziksel tracking yönü ile Unity sahnesindeki XR Origin yönünün hizalı olmamasından kaynaklanmıştır. Bu durumda Main Camera rotation değerini değiştirmek yerine XR Origin rotation değerinin düzenlenmesi ve gerekirse yaw correction uygulanması gerekmektedir.
- Kamera titremesi

Headset’in küçük hareketlerinde görüntünün aşırı titremesi tracking jitter, Character Controller düzeltmeleri, XR Body Transformer etkisi veya yanlış parent/scale yapısından kaynaklanabilmektedir. Bu nedenle XR Origin’in root yapıda olması, XR Device Simulator’ın gerçek headset testlerinde kapalı tutulması, Character Controller ayarlarının kontrol edilmesi ve
gereksiz | body | transformer | müdahalelerinin | sınırlandırılması
gerekmektedir [18][19].
- VR giriş ekranında butonlara tıklanamaması

VR giriş ekranındaki butonların tıklanamaması, Canvas render mode, raycaster yapısı ve EventSystem input modülü ile ilişkilidir. Bu sorunun çözümü için World Space Canvas kullanılması, Tracked Device Graphic Raycaster bileşeninin eklenmesi ve XR UI Input Module üzerinden VR controller girişlerinin UI sistemine bağlanması gerekmektedir.

- GitHub Desktop ile değişikliklerin görünmemesi

Unity’de yapılan sahne değişikliklerinin GitHub Desktop üzerinde
görünmemesi | çoğunlukla | sahnenin | kaydedilmemesinden
kaynaklanmaktadır. | Unity | sahnesi | kaydedilmediğinde | ilgili | .unity
dosyasında değişiklik oluşmadığı için GitHub Desktop bu değişimi algılamaz. Bu nedenle VR ayarları ve sahne düzenlemeleri sonrasında
sahnenin | kaydedilmesi, | özellikle | SampleScene.unity | gibi | sahne
dosyalarının commit’e dahil edilmesi gerekmektedir.
Bu problemler ve çözüm yaklaşımları, VR geçiş sürecinde yalnızca paket kurulumunun yeterli olmadığını göstermiştir. Donanım runtime ayarları, Unity XR ayarları, sahne hiyerarşisi, input sistemi ve versiyon kontrol süreçleri birlikte ele alındığında sistem daha kararlı ve takım çalışmasına uygun bir yapıya kavuşturulabilmektedir.

### 2.3. Görüntü İşleme ve Yapay Zekâ Tabanlı Algılama Sistemi

### 2.3.1. Görüntü işleme alt sisteminin amacı

Bu projede geliştirilen görüntü işleme alt sistemi, VR ortamında seçilen cerrahi aletin fiziksel ortamda algılanması, sınıflandırılması ve robotik kolun doğru hedefe yönlendirilmesi amacıyla tasarlanmıştır. Sistem, çalışma alanında bulunan cerrahi aletleri gerçek zamanlı olarak analiz ederek her nesnenin sınıf bilgisini ve görüntü üzerindeki konumunu elde etmektedir. Elde edilen bu bilgiler daha sonra mikrodenetleyici tabanlı kontrol sistemine aktarılmakta ve robotik kolun karar mekanizmasında kullanılmaktadır.

Bu yapı sayesinde sistem yalnızca mekanik hareket gerçekleştiren bir robot kol olmaktan çıkmakta; çevresini algılayabilen, hedef nesneyi tanıyabilen ve VR ortamındaki seçim ile fiziksel nesneler arasında eşleştirme yapabilen akıllı bir yapıya dönüşmektedir [21]. Geliştirilen görüntü işleme tabanlı akıllı robotik sistem, temel olarak şu fonksiyonel işlem adımlarını gerçekleştirmektedir:

- Gerçek Zamanlı Nesne Algılama ve Sınıflandırma: Ameliyat esnasında cerrahi aletlerin kamera görüntülerinden anlık olarak tespit edilmesi ve ilgili nesne sınıflarına ayrılması,
- Sınırlandırıcı Kutu (Bounding Box) Koordinatlarının Elde Edilmesi: Algılanan cerrahi aletlerin görüntü uzayındaki konumlarının, sınırlandırıcı kutu koordinatları veri matrisi olarak çıkarılması,
- Mikrokontrolcüler Arası Kablosuz Veri İletişimi: Elde edilen algılama ve koordinat verilerinin, ESP32 modülü üzerinden seri haberleşme protokolleri vasıtasıyla ana denetleyici olan Arduino Mega'ya aktarılması,
- Sanal Gerçeklik (VR) Entegrasyonu ve Hedef Doğrulama: Sanal gerçeklik ortamından gelen hedef referans bilgisi ile görüntü işlemeden elde edilen anlık algılama sonuçlarının karşılaştırılarak doğrulanması,
- Kinematik Kontrol ve Robotik Yönlendirme: Doğrulanan hedef verileri doğrultusunda, robotik kolun ilgili hedef koordinatına hassas ve doğru bir şekilde yönlendirilmesi.

### 2.3.2. Kullanılan görüntü işleme donanımları

Projede görüntü işleme altyapısının oluşturulabilmesi için çeşitli gömülü sistem donanımları kullanılmıştır. Bu donanımların temel amacı, fiziksel ortamdan görüntü alınması, görüntünün işlenmesi ve elde edilen verilerin robotik kontrol sistemine aktarılmasıdır. Geliştirilen gömülü sistem mimarisinde kullanılan temel donanım bileşenleri ve arayüzleri aşağıda sıralanmıştır:

- Grove Vision AI Modülü ve Entegre Kamera: Gerçek zamanlı nesne algılama ve yapay zekâ tabanlı görüntü işleme çıkarımlarının (inference) donanım seviyesinde koşturulmasını sağlayan ana uç birim (edge AI) bileşeni,
- ESP32 Geliştirme Kartı: Yüksek hızlı veri işleme, kablosuz haberleşme protokollerinin yönetimi ve mikrokontrolcüler arası köprü veri transferini üstlenen denetleyici birim,
- Arduino Mega Ana İşlem Platformu: Robotik kolun motor sürücü kontrolü, kinematik hesaplamaları ve genel sistem senkronizasyonunu yürüten ana mikrokontrolcü,
- Haberleşme Arayüzleri (UART ve I2C): Modüller arası veri paketlerinin kararlı ve düşük gecikmeli olarak aktarılmasını sağlayan seri çevre birimleri (chassis-level) haberleşme hatları,
- Çevresel Bağlantı ve Güç Altyapısı: Sistem içi veri hatlarının sürekliliğini sağlayan USB bağlantı kabloları ile mikrokontrolcü ve aktüatörlerin akım-gerilim kararlılığını koruyan izole harici güç kaynakları.

Grove Vision AI modülü, yapay zekâ destekli nesne algılama işlemlerini gerçekleştiren temel görüntü işleme birimidir [22]. ESP32 ise Grove Vision AI ile Arduino Mega arasında haberleşme köprüsü olarak görev yapmaktadır. Arduino Mega tarafında ise görüntü işleme verileri değerlendirilerek robotik kolun hareket algoritmaları çalıştırılmaktadır.

### 2.3.3. Grove Vision AI modülünün sistemdeki görevi

Projede nesne algılama işlemleri için Grove Vision AI modülü kullanılmıştır. Bu modül, gömülü yapay zekâ uygulamaları için optimize edilmiş bir görüntü işleme platformudur. Modül üzerinde çalışan yapay zekâ modeli sayesinde görüntü doğrudan cihaz üzerinde analiz edilmekte ve nesne algılama sonuçları elde edilmektedir. Sistem mimarisinde bir uç yapay zekâ (Edge AI) birimi olarak konumlandırılan Grove Vision AI modülünün üstlendiği temel görev ve operasyonlar aşağıda sıralanmıştır:

- Görüntü Yakalama (Image Acquisition): Entegre kamera sensörü aracılığıyla ameliyat sahasından yüksek çözünürlüklü ve gerçek zamanlı video akışının alınması,
- Donanım Seviyesinde Çıkarım (Hardware Inference): Google Colab ortamında eğitilen ve TensorFlow Lite formatına dönüştürülen derin öğrenme tabanlı nesne algılama modelinin modül üzerinde otonom olarak koşturulması,

- Cerrahi Nesne Sınıflandırma: Görüntü matrisindeki öznitelikleri analiz ederek ameliyatta kullanılan cerrahi aletlerin önceden tanımlanmış sınıflara göre ayırt edilmesi,
- Olasılıksal Güven Skoru (Confidence Score) Hesabı: Algılanan her bir cerrahi aletin, ilgili sınıfa ait olma olasılığının matematiksel bir doğruluk yüzdesi (%0-100) olarak hesaplanması,
- Sınırlandırıcı Kutu (Bounding Box) Regresyonu: Tespit edilen cerrahi nesnelerin görüntü uzayındaki pikselsel konumlarını belirleyen iki boyutlu koordinat vektörlerinin üretilmesi,
- Çıkarım Sonuçlarının Çevresel Aktarımı: Elde edilen sınıf, güven skoru ve koordinat verilerinin, sonraki işlem basamakları için ara birim denetleyicisi olan ESP32 modülüne seri haberleşme hatları üzerinden gerçek zamanlı iletilmesi.

Bu çalışmada temel olarak “hemostat” ve “penset” sınıfları üzerinde durulmuştur. Model çıktılarında her nesne için sınıf bilgisi, güven skoru ve konum verileri elde edilmiştir.

### 2.3.4. Veri seti hazırlama ve etiketleme süreci

Yapay zekâ modelinin eğitilebilmesi için öncelikle cerrahi aletlere ait bir görüntü veri seti oluşturulmuştur. Veri setinde farklı açılar, ışık koşulları ve konumlarda çekilmiş görüntüler kullanılmıştır. Bu yaklaşım sayesinde modelin farklı ortam koşullarında daha kararlı çalışması hedeflenmiştir.Veri seti hazırlama süreci şu adımlardan oluşmaktadır:

1. Cerrahi aletlerin görüntülerinin elde edilmesi.
2. Görsellerin Roboflow platformuna yüklenmesi.
3. Bounding box ile nesne etiketleme işlemlerinin yapılması.
4. Sınıf isimlerinin tanımlanması.
5. Eğitim, doğrulama ve test veri gruplarının oluşturulması.
6. Görsellerin model giriş boyutuna uygun şekilde yeniden boyutlandırılması.
7. Veri setinin YOLO formatında dışa aktarılak eğitime hazır hale getirilmesi.

Etiketleme işlemi sırasında her nesnenin görüntü üzerindeki sınırları dikdörtgen kutular ile belirlenmiştir. Böylece model yalnızca nesnenin hangi sınıfa ait olduğunu değil, görüntü üzerinde nerede bulunduğunu da öğrenmiştir. Bounding box koordinat sisteminde başlangıç noktası görüntünün sol üst köşesi olarak kabul edilip x ekseni soldan sağa, y ekseni ise yukarıdan aşağıya doğru artmaktadır.

### 2.3.5. Google Colab ortamında model eğitimi

Nesne algılama modelinin eğitimi için Google Colab platformu kullanılmıştır. Google Colab, GPU destekli bulut tabanlı bir geliştirme ortamı sunduğu için model eğitim sürecinin daha hızlı gerçekleştirilmesine imkân sağlamıştır. Bulut tabanlı Google Colab platformu üzerinde gerçekleştirilen model eğitim, optimizasyon ve dönüştürme aşamaları aşağıda detaylandırılmıştır:

- Çalışma Ortamının Hazırlanması ve Bağımlılıkların Kurulması:
Derin | öğrenme | mimarisinin | ihtiyaç | duyduğu | temel | Python
kütüphanelerinin ve framework'lerinin çalışma ortamına entegre edilmesi,
- Veri Setinin İçe Aktarılması: Roboflow platformu üzerinde etiketlenen ve dışa aktarılan özgün cerrahi alet veri setinin bulut ortamına transfer edilmesi,
- Konfigürasyon Dosyasının Yapılandırılması: Nesne sınıflarını ve veri yollarını (path) tanımlayan data.yaml dosyasının, eğitim mimarisine uygun olarak manipüle edilmesi ve düzenlenmesi,
- Hiperparametrelerin Optimizasyonu: Modelin yakınsama hızını ve başarısını doğrudan etkileyen epoch, batch size ve öğrenme oranı (learning rate) gibi hiperparametrelerin belirlenmesi,
- YOLO Tabanlı Evrişimli Sinir Ağının Eğitilmesi: Belirlenen parametreler doğrultusunda, nesne tespiti için seçilen YOLO mimarisinin transfer öğrenme yöntemiyle eğitilmesi,
- Performans Metriklerinin Analizi: Eğitim sürecinin sonunda elde edilen kayıp (loss) grafiklerinin, kesinlik (precision), duyarlılık (recall) ve mAP (mean Average Precision) doğruluk metriklerinin incelenmesi,
- En İyi Model Ağırlıklarının Çıkarılması: Doğrulama (validation) aşamasında en yüksek başarıyı gösteren optimum model ağırlıklarının (best.pt) sistemden dışa aktarılması,
- Uç Cihaz Dönüşümü (TensorFlow Lite Optimizasyonu): Gömülü sistemde (Grove Vision AI) gerçek zamanlı ve düşük gecikmeli çıkarım (inference) gerçekleştirebilmek adına modelin TensorFlow Lite (.tflite) formatına kuantize edilerek dönüştürülmesi.

Model eğitim sürecinde sınıf eşleşmelerinin doğru yapılması kritik önem taşımaktadır [23]. Örneğin “hemostat” sınıfının 0, “penset” sınıfının 1 olarak tanımlanması durumunda aynı eşleşmenin mikrodenetleyici tarafında da korunması gerekmektedir.

### 2.3.6. TensorFlow Lite model dönüşüm süreci

Eğitilen modelin gömülü sistemlerde çalışabilmesi amacıyla TensorFlow Lite formatına dönüştürülmesi gerekmiştir. TensorFlow Lite, mobil ve gömülü sistemlerde düşük işlem gücü ve düşük bellek kullanımı ile çalışabilen optimize edilmiş bir yapay zekâ formatıdır. YOLO modelinin gömülü mimariye uyarlanması sürecinde gerçekleştirilen optimizasyon boru hattı (pipeline) şu teknik adımları içermektedir:

- Eğitimi tamamlanmış özgün YOLO model ağırlıklarının çalışma ortamına dahil edilmesi,
- Model grafik yapısının TensorFlow mimarisine dönüştürülmesi,
- Uç cihaz uyumluluğu için .tflite uzantılı TensorFlow Lite dosya formatının üretilmesi,
- Giriş ve çıkış tensör (tensor dimensions) veri yapılarının ve boyutlarının doğrulanması,
- Hesaplama | maliyetini | düşürmek | amacıyla | model | bileşenlerine
kuantizasyon algoritmalarının uygulanması,
- Bellek ve işlemci optimizasyonu sağlayan INT8 (8-bit Integer) formatındaki nihai derin öğrenme modelinin üretilmesi.

Grove Vision AI modülünün gömülü yapay zekâ hızlandırıcısı ile uyumlu çalışabilmesi için modelin INT8 quantization formatında olması gerekmektedir [24]. Bu işlem model boyutunu küçültmekte ve gömülü sistem performansını artırmaktadır.

### 2.3.7. Modelin Grove Vision AI modülüne yüklenmesi

TensorFlow Lite formatına dönüştürülen model, daha sonra Grove Vision AI modülüne yüklenmiştir. Bu süreçte SenseCraft AI platformu kullanılmıştır. Optimize edilen derin öğrenme modelinin hedef donanıma yüklenmesi ve gerçek zamanlı test süreçleri şu iş adımlarını kapsamaktadır:

- Donanım Bağlantısının Kurulması: Fiziksel katmanda veri aktarımını sağlamak amacıyla Grove Vision AI uç birim modülünün, ana bilgisayar arayüzüne (host PC) uygun veri kabloları ile entegre edilmesi,

- Bulut Tabanlı Dağıtım Platformunun Yapılandırılması: Modül yazılımı (firmware) ve yapay zekâ modellerinin yönetimi için SenseCraft AI grafik kullanıcı arayüzü (GUI) ve dağıtım platformunun aktif hale getirilmesi,
- Model Dağıtımı (Deployment): TensorFlow Lite formatındaki optimize edilmiş özgün ağırlık matrisinin, platform aracılığıyla donanım üzerindeki flaş belleğe (on-board flash memory) transfer edilmesi,
- Sınıf Etiketlerinin Senkronizasyonu: Modelin çıkış katmanındaki sınıf indekslerinin, cerrahi alet taksonomisiyle donanım seviyesinde doğru eşleştiğinin kontrol edilmesi ve doğrulanması,
- Gerçek Zamanlı Çıkarım (Canlı Test): Entegre kamera sensöründen alınan anlık video akışı üzerinden modelin otonom olarak test edilmesi ve
dinamik | ortam | koşullarında | nesne | algılama | performansının
gözlemlenmesi,
- Çıkarım Başarımının Analizi: Canlı testler esnasında elde edilen bounding box doğruluğu, sınıflandırma kararlılığı ve güven skorlarının, sistem isterleri doğrultusunda nitel ve nicel olarak incelenmesi.

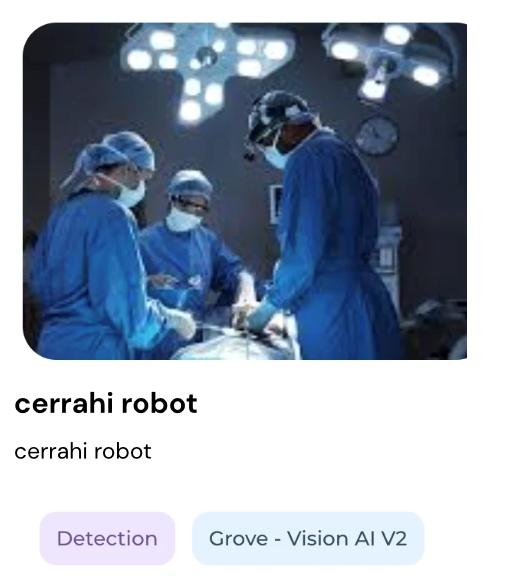
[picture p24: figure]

Şekil 22 Oluşturulan Grove Vision AI Modeli

Şekil 22’de oluşturulan Grove Vision AI modelinin yalnızca bilgisayar ortamında çalışması yeterli olmamaktadır. Modelin aynı zamanda gömülü cihaz üzerinde de stabil şekilde çalışabilmesi gerekmektedir. Bu nedenle giriş boyutları, quantization formatı ve model mimarisi dikkatli şekilde kontrol edilmiştir.

Eğitilen ve INT8 formatına kuantize edilen Grove Vision AI üzerindeki gerçek zamanlı test sonuçları aşağıdaki şekilde sunulmuştur. Geliştirilen bilgisayarlı görü algoritması; ameliyat sahasında bulunan kontamine kompres, steril kompres, hemostat ve penset gibi kritik cerrahi aletleri yüksek kararlılıkla tespit edebilmektedir. Modül, nesneleri doğru taksonomik sınıflara atamanın yanı sıra, her bir aletin etrafına dinamik sınırlandırıcı kutular çizerek pikselsel konumlandırma gerçekleştirmektedir. Kutuların üzerinde yer alan güven skorları (Örn: penset için %86, steril kompres için %83), modelin gerçek zamanlı ve değişken ışık koşulları altındaki yüksek çıkarım başarısını doğrulamaktadır. Sistem, elde ettiği bu uzamsal çıktı katmanını [x_center, y_center, width, height, score, class] veri protokolü yapısında işleyerek bir sonraki katmana aktarmaktadır.

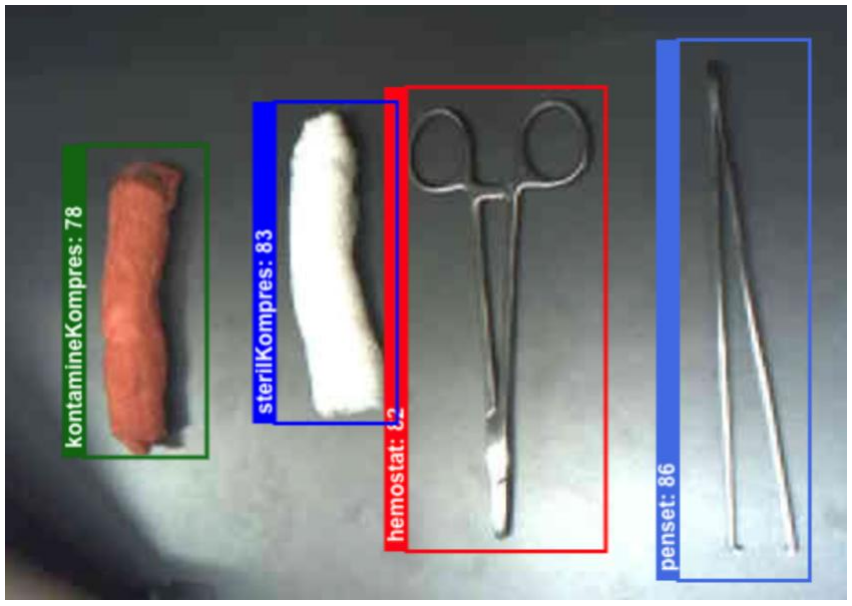
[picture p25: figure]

Şekil 23 Cerrahi Nesnelerin Tespiti ve Ayırımı

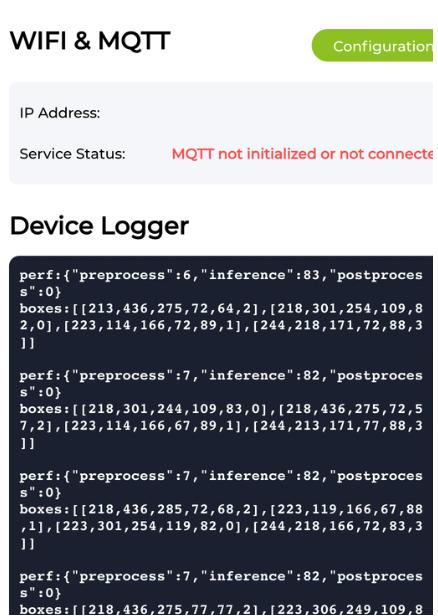
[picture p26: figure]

Şekil 24 Sense Craft Testi

Şekil 23 ve Şekil 24’te, yapay zekâ modelinin donanım üzerindeki çalışma hızını ve ürettiği sayısal verileri göstermektedir. Bu veriler üzerinden sistemin iki kritik başarısı doğrulanmıştır:

- Performans: Görseldeki perf (performans) satırlarına göre; kameradan görüntünün alınması (preprocess) 6-7 milisaniye, yapay zekanın nesneyi tanıma süresi (inference) ise 82-83 milisaniye sürmektedir. Toplamda yaklaşık 90 milisaniyede (saniyede 11 kare hızında) çalışan bu yapı, robotik kolun gecikmesiz çalışabilmesi için gereken gerçek zamanlılık kriterini başarıyla karşılamaktadır.
- Üretilen Ham Veriler: boxes başlığı altındaki sayılar, modelin algıladığı cerrahi aletlerin konum (x, y), boyut (w, h), doğruluk oranı ve sınıf numarasını içeren ham matris çıktısıdır.

### 2.3.8. ESP32’nin görüntü işleme sistemindeki görevi

ESP32 geliştirme kartı, Grove Vision AI ile Arduino Mega arasında haberleşme sağlayan ara kontrol birimi olarak kullanılmıştır. Grove Vision AI tarafından üretilen nesne algılama sonuçları ESP32 tarafından okunmuş ve seri haberleşme üzerinden Arduino Mega’ya aktarılmıştır. Sistem mimarisinde bir ara birim ve veri köprüsü olarak konumlandırılan ESP32 geliştirme kartının üstlendiği temel görev ve operasyonlar aşağıda sıralanmıştır:

- Uç Birim ile Protokol Düzeyinde Haberleşme: Nesne algılama işlemlerini yürüten Grove Vision AI modülü ile I2C veya UART haberleşme arayüzleri üzerinden senkron/asenkron veri bağı kurulması,
- Çıkarım (Inference) Çıktılarının Alınması: Donanım seviyesinde işlenen kamera görüntülerine ait ham nesne algılama verilerinin dinamik olarak okunması,
- Anlamsal Veri Ayrıştırma (Parsing): Okunan ham veriler içerisinden ilgili nesneye ait sınıf kimlik numarası (Class ID) ve iki boyutlu pikselsel sınırlandırıcı kutu (bounding box) koordinat bilgilerinin ayıklanması,
- Seri Paket Entegrasyonu (Data Packaging): Ayrıştırılan sınıf ve konum verilerinin, mikrokontrolcüler arası güvenli aktarım için önceden tanımlanmış bir veri paketi yapısına (başlık, veri gövdesi ve hata kontrol biti - checksum gibi) dönüştürülmesi,
- Mikrokontrolcüler Arası Veri Transferi: Oluşturulan seri veri paketlerinin, donanımsal UART hatları üzerinden ana kontrol birimi olan Arduino Mega platformuna gerçek zamanlı ve düşük gecikmeli olarak iletilmesi,
- Teşhis ve Sistem Doğrulama (Debugging): Geliştirme ve test aşamalarında sistem kararlılığını izlemek adına veri akışının ve hata kodlarının eş zamanlı olarak seri port ekranı üzerinden raporlanması.

ESP32’nin kullanılması, sistemde daha esnek veri işleme ve haberleşme mimarisi oluşturulmasını sağlamıştır [25].

### 2.3.9. Grove Vision AI ve ESP32 haberleşmesi

Grove Vision AI ile ESP32 arasında veri aktarımı için başlangıçta I2C haberleşmesi denenmiştir. Ancak cihazın I2C taramasında algılanmaması ve veri okuma problemleri nedeniyle UART haberleşmesine geçilmiştir. UART haberleşmesinde veri aktarımı TX ve RX pinleri üzerinden gerçekleştirilmektedir. Bu bağlantıda:

- Grove TX → ESP32 RX
- Grove RX → ESP32 TX
- GND → Ortak GND şeklinde bağlantı yapılmıştır. ESP32 mikrokontrolcüsü katmanında yapılandırılan ve Arduino Mega'ya iletilen telemetri paketinin veri mimarisi şu teknik bileşenlerden oluşmaktadır:
- Hedef nesneye ait iki boyutlu lokalizasyon matrisinin x ve y merkez/orijin koordinatları,
- Sınırlandırıcı kutunun uzamsal boyutlarını tanımlayan genişlik ve yükseklik pikselleri,
- Model çıkarımının doğruluğunu simgeleyen olasılıksal güven değeri,
- Cerrahi alet türünü ayrıştıran tamsayı tabanlı kategorik sınıf indeksi (Class ID).

Bu telemetri bileşenleri, veri bütünlüğünün korunması adına belirli bir protokol düzeninde paketlenerek UART donanımsal hattı üzerinden ana işlem birimine iletilmiştir.

### 2.3.10. ESP32 ve Arduino Mega haberleşmesi

ESP32 üzerinden alınan görüntü işleme verileri UART haberleşmesi ile Arduino Mega’ya aktarılmıştır. Arduino Mega üzerinde birden fazla donanımsal seri port bulunduğu için haberleşmede Serial1 hattı kullanılmıştır. Bağlantı yapısı şu şekildedir:

- ESP32 TX → ARDUINO MEGA RX1
- ESP32 RX → ARDUINO MEGA TX1
- Ortak GND bağlantısı

Arduino Mega tarafında gelen görüntü işleme verileri değerlendirilerek VR ortamından gelen hedef bilgisi ile karşılaştırılmıştır. Bu yapı sayesinde algılanan nesne sınıfı belirlenebilmekte, hedef nesne eşleşmesi yapılabilmekte ve robotik kolun doğru hedefe yönlendirilmesi sağlanabilmektedir.

### 2.3.11. VR seçimi ile görüntü işleme verisinin eşleştirilmesi

Projede kullanıcı VR ortamında bir cerrahi alet seçmektedir. Bu seçim bilgisi XBee üzerinden Arduino Mega’ya aktarılmaktadır. Aynı anda kamera sistemi fiziksel ortamı analiz ederek algılanan nesnelerin bilgilerini göndermektedir. Sistemin ana işlem birimi olarak konumlandırılan Arduino Mega platformunda yürütülen merkezi kontrol ve karar mekanizması şu ardışık adımlardan oluşmaktadır:

- Referans Hedef Verisinin Alınması: Sanal gerçeklik ortamında kullanıcı tarafından seçilen hedef nesneye ait kategorik sınıf referans bilgisinin sisteme dinamik olarak dahil edilmesi,
- Algılama Çıktılarının Telemetri Okuması: ESP32 ara birim denetleyicisi üzerinden aktarılan ve kamera görüş alanındaki cerrahi aletlere ait anlık nesne/konum verilerinin eş zamanlı olarak okunması,
- Mantıksal Korelasyon ve Sınıf Karşılaştırması: VR ortamından gelen referans hedef sınıf bilgisi ile görüntü işleme katmanından elde edilen anlık sınıf kimliklerinin (Class ID) mantıksal olarak karşılaştırılması,
- Uzamsal Koordinat Verilerinin Filtrelenmesi: Sınıf eşleşmesinin doğrulanması durumunda, hedef nesneye ait iki boyutlu sınırlandırıcı kutu (bounding box) koordinat verilerinin kinematik hesaplamalar için işleme alınması,
- Kinematik Yönlendirme ve Aktüatör Kontrolü: Elde edilen uzamsal konum verileri doğrultusunda, robotik kolun eklem açılarının hesaplanarak ilgili hedef cerrahi alete doğru hassas bir şekilde yönlendirilmesi.

Geliştirilen bu kontrol mimarisi sayesinde sistem, pasif ve rastgele bir nesne algılama yapısı olmaktan çıkarak sanal gerçeklik arayüzü ile fiziksel robotik aktüatörler arasında köprü kuran, kullanıcı geribildirimlerine göre dinamik olarak şekillenen hedef odaklı akıllı bir tanıma ve konumlandırma algoritmasına dönüşmüştür.

### 2.3.12. Bounding box ve koordinat hesaplamaları

Nesne algılama modelinin çıktısı yalnızca sınıf bilgisinden oluşmamaktadır. Aynı zamanda nesnenin görüntü üzerindeki konumu da belirlenmektedir. Bu konum bilgisi bounding box yapısı ile ifade edilmektedir. Bilgisayarlı görü algoritmasının çıktı katmanını (output layer) oluşturan sınırlandırıcı kutu (bounding box) vektörü şu teknik parametreleri içermektedir:

- Nesne lokalizasyonunun yatay eksendeki piksel referansını tanımlayan x koordinatı,
- Nesne lokalizasyonunun dikey eksendeki piksel referansını tanımlayan y koordinatı,
- Sınırlandırıcı çerçevenin yatay pikselsel genişliğini belirten genişlik parametresi,
- Sınırlandırıcı çerçevenin dikey pikselsel yüksekliğini belirten yükseklik parametresi,

- Çıkarımın matematiksel kesinliğini ve doğruluğunu simgeleyen istatistiksel güven skoru,
- Tespit edilen cerrahi enstrüman türünü ayırt eden numerik sınıf kimliği.

Nesnenin merkez noktası aşağıdaki şekilde hesaplanabilmektedir:

x_{merkez]=x+

w
2

(1)

y_{merkez]=y+

ℎ
2

(2)

Burada;

- x ve y: Sınırlandırıcı kutunun sol üst köşesinin pikselsel orijin koordinatlarını, (1)(2)
- w: Kutunun pikselsel genişliğini, (1)
- ℎ: Kutunun pikselsel yüksekliğini ifade etmektedir. (2)

Elde edilen bu nihai uzamsal veriler, robotik kolun ters kinematik (inverse kinematics) ve hedef yönlendirme algoritmalarına referans girdisi olarak aktarılmakta; böylece aktüatörlerin hedef nesneye otonom, hassas ve dinamik olarak konumlanması sağlanmaktadır.

### 2.3.13. Veri gönderim sıklığı ve sistem performansı

Cerrahi aletlerin çalışma alanında genellikle sabit konumda bulunması nedeniyle görüntü işleme sisteminden sürekli veri gönderilmesi yerine belirli aralıklarla veri aktarılması tercih edilmiştir. Bu yaklaşım sayesinde:

- Arduino Mega üzerindeki işlem yükü azaltılmış,
- Seri haberleşme hattındaki yoğunluk düşürülmüş,
- Robotik kol kontrolü daha kararlı hale getirilmiş,
- Sistem gecikmeleri azaltılmıştır.

Bu nedenle ESP32 tarafında belirli zaman aralıklarında veri gönderimi gerçekleştirilmiştir.

### 2.3.14. Görüntü işleme sisteminin genel veri akışı

### 1. Sistemin genel çalışma akışı aşağıdaki gibidir:

2. Kamera fiziksel ortamdan görüntü alır.
3. Grove Vision AI görüntüyü analiz eder.
4. Cerrahi alet sınıfı ve koordinat bilgisi elde edilir.
5. ESP32 bu verileri okur.
6. Veriler UART üzerinden Arduino Mega ’ya gönderilir.
7. Arduino Mega VR hedef bilgisi ile algılama sonucunu karşılaştırır.
8. Eşleşme varsa robotik kol hedefe yönlendirilir.

Bu yapı sayesinde görüntü işleme sistemi ile robotik kontrol sistemi gerçek zamanlı olarak birlikte çalışabilmektedir.

### 2.3.15. Sonuç ve değerlendirme

Bu çalışmada görüntü işleme alt sistemi, VR destekli robotik cerrahi eğitim sistemi içerisine entegre edilmiştir. Grove Vision AI, ESP32, Arduino Mega, TensorFlow Lite ve Google Colab kullanılarak gömülü yapay zekâ tabanlı bir nesne algılama sistemi geliştirilmiştir. Hazırlanan veri seti ile nesne algılama modeli eğitilmiş, model TensorFlow Lite formatına dönüştürülmüş ve Grove Vision AI üzerinde çalıştırılmıştır. ESP32 üzerinden alınan algılama sonuçları Arduino Mega’ya aktarılmış ve VR ortamındaki hedef seçimleri ile eşleştirilmiştir. Sonuç olarak geliştirilen görüntü işleme sistemi, robotik kolun fiziksel ortamı algılayabilmesini sağlayarak projeye akıllı algılama yeteneği kazandırmıştır. Bu yapı sayesinde sistem, kullanıcı tarafından seçilen cerrahi aleti fiziksel ortamda tanıyabilen ve robotik hareket kararını buna göre verebilen entegre bir eğitim platformuna dönüşmüştür.
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

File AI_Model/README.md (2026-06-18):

# Surgical Instrument Detection Model

This folder contains the object detection models used in the VR-Assisted Robotic Surgical Training Platform.

## Model Files

### best_int8.tflite
Standard INT8 quantized TensorFlow Lite model exported from YOLOv8.

### best_int8_vela.tflite
Vela-optimized model deployed on Grove Vision AI V2.

## Detected Classes

- hemostat
- kontamineKompress
- penset
- sterilKompress

## Training Pipeline

Roboflow Dataset
→ YOLOv8 Training
→ INT8 Quantization
→ TensorFlow Lite Export
→ Vela Optimization
→ Grove Vision AI V2 Deployment

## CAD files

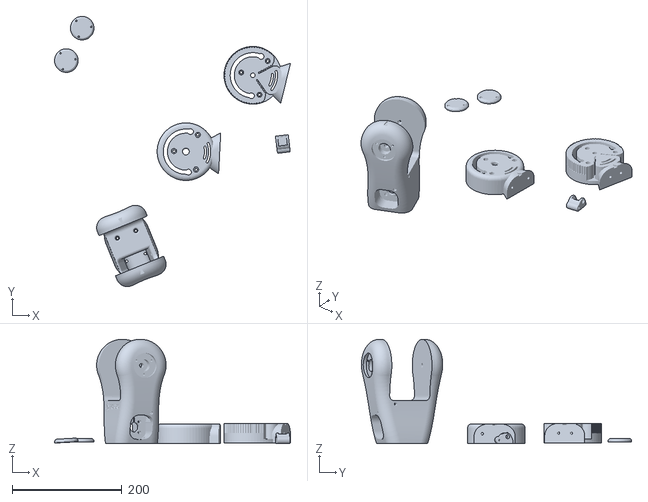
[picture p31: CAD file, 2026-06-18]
dirsek.stl
430.0 x 492.4 x 190.1

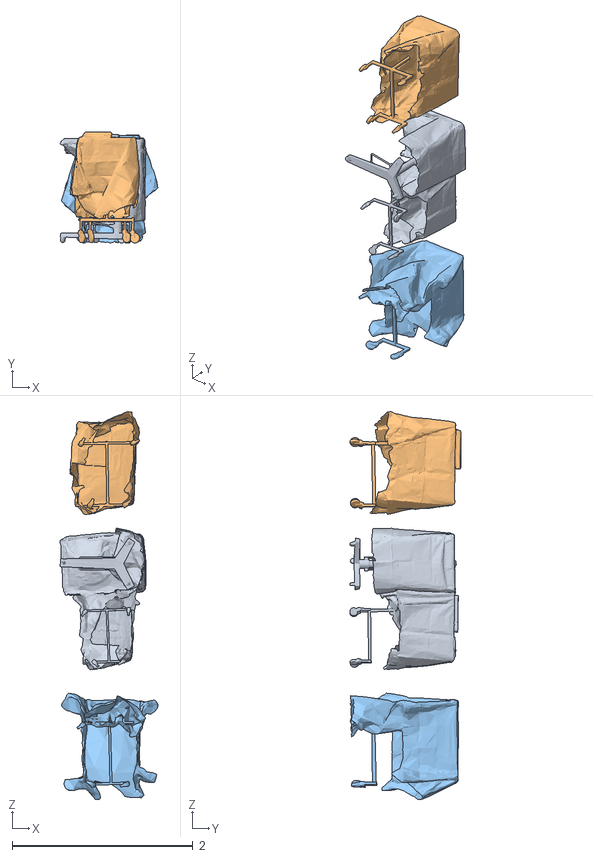
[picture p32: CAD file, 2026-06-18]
Unity/Assets/Modellerim/Masalar/source/Surgical_Table_Single_Collection/Surgical_Table_Single_Collection.obj
1.08 x 1.23 x 4.29
Surgical_Table_Double
Surgical_Table_Single_Cloth
Surgical_Table_Single_Empty

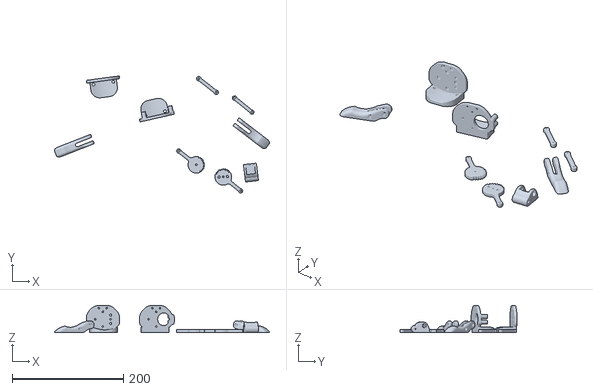
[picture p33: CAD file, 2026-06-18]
gripper.stl
386.1 x 210.1 x 49.0

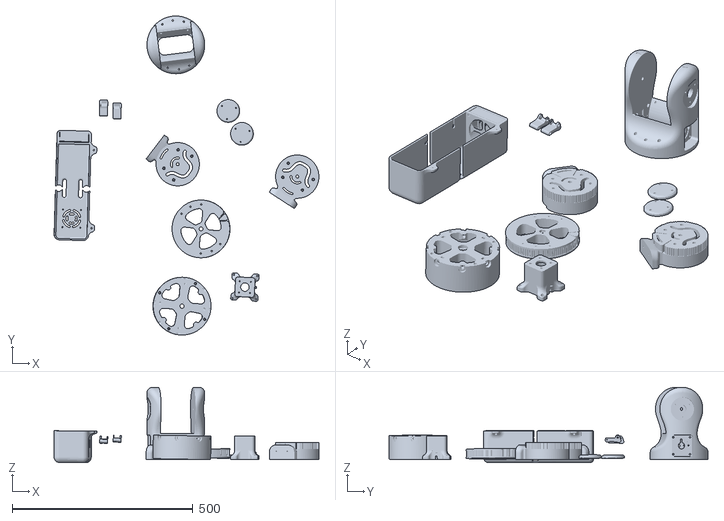
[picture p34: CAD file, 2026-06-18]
taban_omuz.stl
733.7 x 883.6 x 208.8

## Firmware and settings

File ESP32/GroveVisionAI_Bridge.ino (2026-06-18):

/*
========================================================
ESP32 Grove Vision AI Bridge

Project:
VR-Assisted Robotic Surgical Training Platform

Description:
This module interfaces with the Grove Vision AI V2 camera,
receives object detection results, tracks surgical instruments,
and transmits detection data to the Arduino Mega via UART.

Detected Objects:
- Hemostat
- Forceps (Penset)
- Sterile Compress
- Contaminated Compress

Hardware:
- ESP32 Dev Board
- Grove Vision AI V2
- Arduino Mega 2560

Communication:
I2C  : Grove Vision AI <-> ESP32
UART : ESP32 <-> Arduino Mega

========================================================
*/

#include <Arduino.h>
#include <Wire.h>
#include <Seeed_Arduino_SSCMA.h>

SSCMA AI;

const char* classNames[] = {
  "hemostat",
  "kontamineKompress",
  "penset",
  "sterilKompress"
};

struct Detection {
  bool active = false;
  int score = 0;
  int x = 0;
  int y = 0;
  int w = 0;
  int h = 0;
  unsigned long lastSeen = 0;
};

Detection detections[4];

unsigned long lastSendTime = 0;

const unsigned long sendInterval = 500;
const unsigned long timeoutMs = 2000;

void setup() {

  Serial.begin(115200);

  // UART2
  // RX = GPIO16
  // TX = GPIO17
  Serial2.begin(9600, SERIAL_8N1, 16, 17);

  // Grove Vision AI I2C
  Wire.begin(21, 22);

  AI.begin(&Wire);

  Serial.println("Grove Vision AI V2 hazir!");
}

void loop() {

  // Detection oku
  if (!AI.invoke(1, false, false)) {

    for (int i = 0; i < AI.boxes().size(); i++) {

      int t = AI.boxes()[i].target;

      if (t >= 0 && t < 4) {

        detections[t].active = true;

        detections[t].score = AI.boxes()[i].score;

        detections[t].x = AI.boxes()[i].x;
        detections[t].y = AI.boxes()[i].y;

        detections[t].w = AI.boxes()[i].w;
        detections[t].h = AI.boxes()[i].h;

        detections[t].lastSeen = millis();
      }
    }
  }

  // Eski detectionları kapat
  for (int i = 0; i < 4; i++) {

    if (detections[i].active &&
        millis() - detections[i].lastSeen > timeoutMs) {

      detections[i].active = false;
    }
  }

  // Belirli aralıklarla gönder
  if (millis() - lastSendTime >= sendInterval) {

    lastSendTime = millis();

    // =========================
    // MEGA'YA VERİ GÖNDER
    // =========================

    Serial2.print("D;");

    for (int i = 0; i < 4; i++) {

      Serial2.print(i);
      Serial2.print(",");

      Serial2.print(detections[i].active ? 1 : 0);
      Serial2.print(",");

      Serial2.print(detections[i].score);
      Serial2.print(",");

      Serial2.print(detections[i].x);
      Serial2.print(",");

      Serial2.print(detections[i].y);
      Serial2.print(",");

      Serial2.print(detections[i].w);
      Serial2.print(",");

      Serial2.print(detections[i].h);

      if (i < 3) {
        Serial2.print(";");
      }
    }

    Serial2.println();

    // =========================
    // ESP32 SERIAL MONITOR
    // =========================

    Serial.print("Tespitler: ");

    for (int i = 0; i < 4; i++) {

      Serial.print(classNames[i]);
      Serial.print(": ");

      if (detections[i].active) {

        Serial.print("skor=");
        Serial.print(detections[i].score);

        Serial.print(" x=");
        Serial.print(detections[i].x);

        Serial.print(" y=");
        Serial.print(detections[i].y);

        Serial.print(" w=");
        Serial.print(detections[i].w);

        Serial.print(" h=");
        Serial.print(detections[i].h);
      }
      else {

        Serial.print("yok");
      }

      if (i < 3) {
        Serial.print("  ||  ");
      }
    }

    Serial.println();
  }
}

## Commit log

2026-06-18 Create GroveVisionAI_Bridge.ino
    Add ESP32 vision communication module
2026-06-18 Add Unity VR simulation project
    [Surgical_Table_Single_Collection.obj]
